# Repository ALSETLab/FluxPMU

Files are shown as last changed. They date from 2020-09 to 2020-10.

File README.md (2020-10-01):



# FluxPMU - An Open Source Maker's Guide of an DIY PMU
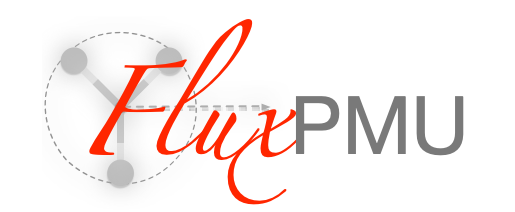
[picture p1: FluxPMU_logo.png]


FluxPMU is a "grassroots" educational project that aims  to  enable  students  to  explore  and  buildan  open  source,  low  cost  PMU.  

Building  from  the  legacy  of [OpenPMU  V1](https://ieeexplore.ieee.org/document/6463452),  FluxPMU  provides  a Do-it-Yourself (DIY) guide with  all  documentation  and  software  sources  required  to  build FluxPMU.

FluxPMU provides only a refinement of OpenPMU V1's design, and it is NOT to be viewed as an evolution on the design of OpenPMU. For the latest iteration of the OpenPMU device, please visit: [http://www.openpmu.org/](http://www.openpmu.org/).

## Cite this work:

This repository is accompanied by a draft of the paper:
> E. Williamson, L. Vanfretti, P. Adhikari, J. W. Dziuba, and D. Laverty, “FluxPMU - A Maker’s Guide of a DIY Synchronized Phasor Measurement Unit,” submitted for review, IEEE PES ISGT NA 2021, Feb. 15-18, Virtual Event, 2021.

The paper can be found on this ``root`` directory, it is named [20200930_Overview_draft.pdf](https://github.com/ALSETLab/FluxPMU/blob/master/20200930_Overview_draft.pdf). The paper has been submitted for review to the [IEEE PES ISGT NA 2021](https://ieee-isgt.org/), if and when the paper is published, this repository will be updated to provide a link to the final version of the paper.

When citing the paper above, we also recommend citing the following publication:
> D. M. Laverty, R. J. Best, P. Brogan, I. Al Khatib, L. Vanfretti and D. J. Morrow, "The OpenPMU Platform for Open-Source Phasor Measurements," in IEEE Transactions on Instrumentation and Measurement, vol. 62, no. 4, pp. 701-709, April 2013, doi: 10.1109/TIM.2013.2240920.

## Repository Organization

### Where to start?
After reading the paper(s) listed above, the entire "Maker's Guide" can be found in the director ``./00_Documentation/00_Makers Guide.pdf``, this will give you an overview of the different resources associated with this repository.

### Organization
This repository contains more than the main "Maker's Guide", it also provides updated source code for all software required for the FluxPMU, documentation for the software, hardware assembly guides, etc.

The resources have been organized as follows:
  - ``00_Documentation`` this is the major folder, it includes the "Maker's Guide" as a single .pdf, [20200930_Overview_draft.pdf](https://github.com/ALSETLab/FluxPMU/blob/master/20200930_Overview_draft.pdf), and three sub-folders. The sub-folders include:
      - ``01_HardwareGuides`` contains assembly instructions, PIC micro-controller configuration, wiring, etc.
      - ``02_TestingGuides`` contains documents showing how to test the FluxPMU using different instruments such as a frequency generator, an Analog Discovery Board, etc.
      - ``03_LabVIEW_VI_Documentation`` contains individual documentation for all LabVIEW VI files in .pdf. You can also find this documentation [online](https://alsetlab.github.io/S3DK/docs/Code_Flow_Chart.html), however, it is also placed here for version tracking and maintainance purposes.
  - ``01_SourceCode`` contains two folders, one with all the updated (64-bit) software related to LabVIEW and the PIC micro-controller (v5p1) files used.
  - ``02_HardwareSourceFiles`` contains a part list/bill of materials with costs based on US-based suppliers and costs in US dollars, as well as the design BRD files for the PCBs.
  - ``10_LegacyDocumentation`` contains the original documents we used when getting FluxPMU started.

## Acknowledgement
This work was supported in part by Dominion Energy Virginia and in part by the Center of Excellence for NEOM Research at the King Abdullah University of Science and Technology under grant OSR-2019-CoE-NEOM- 4178.12.

## No Warranty
(c) David Laverty, Emmett Williamson, Luigi Vanfretti, Prottay M. Adhikari, Jerry W. Dziuba.

All materials under this repository are distributed under the GPL v3 license.

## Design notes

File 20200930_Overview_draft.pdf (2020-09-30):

# FluxPMU — A Maker’s Guide of a DIY Synchronized Phasor Measurement Unit

Emmett Williamson, Luigi Vanfretti, Prottay M. Adhikari, Jerry W. Dziuba
ECSE Department
Rensselaer Polytechnic Institute Troy, NY, USA
email: emmettact@gmail.com, vanfrl@rpi.edu, mondap2@rpi.edu, dziubj@rpi.edu

David Laverty
Energy, Power and Intelligent Control Queen’s University Belfast Belfast, UK
email: david.laverty@qub.ac.uk

Abstract—Synchrophasor technology is transforming the way the power grid is being monitored thanks to the benefits provided by synchronized Phasor Measurement Units (PMUs). To exploit these benefits, future power engineers need better understanding of how PMUs work at all levels, from hardware components to phasor estimation methods implemented in software. However, hands-on experiences with these technologies allowing students to ”tinker” with a PMU are limited. The FluxPMU project aims to enable students to explore and build an open source, low cost PMU. Building from the legacy of OpenPMU V1, FluxPMU provides a Do-it-Yourself (DIY) guide with all documentation and software sources required to build the FluxPMU, which can be found in the following Github repository: https://github.com/alsetlab/fluxpmu. This paper summarizes the authors’ efforts in creating this Maker’s Guide.

I. INTRODUCTION
A. Motivation

Major power system outages, such as 2003 Northeast Blackout [1], 2012 India Blackout [2], 2014 Bangladesh Blackout [3], 2019 London Blackout [4], have highlighted the advantages of high update rate and time synchronized measurements for system awareness. One of the main ways this is achieved is through Phasor Measurement Units (PMUs), which produce time sycnhronized synchrophasor measurements. It has been suggested that, implementing more Phasor Measurement Units (PMUs) could have helped control the power loss by providing grid operators with more information in all those cases. It is to be noted that, although nine PMUs were in use during the blackout reported in [2], two of them (in crucial locations) were not connected to communicate with control centers. The reports associated with these blackouts, suggest that these systems lacked situational awareness and system visibility . As the number of installed PMUs increases in the United States [7], modern PMUs are considered to be a black box of digital signal processing. For instance, industry grade protective relays with PMU functionalities or standard PMUs provide the necessary functionalities, but are difficult to adopt for teaching applications as it is challenging to tinker with their

This work was supported in part by Dominion Energy Virginia and in part by the Center of Excellence for NEOM Research at the King Abdullah University of Science and Technology under grant OSR-2019-CoE-NEOM-4178.12.

internal hardware and functions beyond configuration changes without risking potential damage. Another constraint is that the cost of industry-standard PMUs are over $7000 USD [8], which is too expensive for educational purposes. Additionally, an industrial grade PMU requires special setup to be safe. Using main power line voltage, current and power, poses safety requirements difficult to fulfill in a classroom setting.
The main requirements to consider for an educational PMU are: (i) low cost, (ii) ability to expose students to hands-on learning on the inner workings of the devices, (iii) safety, and (iv) adequate documentation. While the industry grade devices offer plentiful documentation, they do not fulfill requirements (i)-(iii). On the other hand, several open source PMUs that have been created could offer a solution to the cost, but lack the documentation for students use. FluxPMU aims to solve these issues.
FluxPMU is an open-source, low-cost PMU suitable for educational purposes. Being an open source hardware-software solution, FluxPMU would enable the students to explore and modify the entire signal path. Students will have the opportunity to configure and readjust hardware components like CTs and PTs, burden resistors, etc. It is also possible to have direct access to the ADC stage, where analog signals are converted into digital measurements. Apart from hardware and software, the FluxPMU project consists of a documentation dedicated to the build process. The documentation was written specifically to be used by students to ameliorate the build process, and help improve the understanding of each component, and how a PMU works. However, it must be noted that this implementation requires the students to have electrical safety training, as it involves working with high voltages.
B. Previous and Related Work
FluxPMU is based on OpenPMU V1 [9], [15], [16]. OpenPMU V1 has the main benefit from educational purposes to expose the student to all software and hardware aspects that need to be considered for a functional PMU. National Instruments has archived the OpenPMU V1 project [24] in their library. The authors have collaborated to build on the legacy of OpenPMU V1 for educational purposes, and thus, the hardware and software is nearly identical between FluxPMU and OpenPMU. The main difference is that the documentation provided by FluxPMU will offer a more comprehensive guide specifically tailored for students and educational purposes. The main criticism of OpenPMU V1 [11] and thereby of FluxPMU is that of the use of a National Instruments (NI) 6009 Data Acquisition (DAQ) and the NI LabVIEW [10] software being proprietary. While the dependency on the NI 6009 still remains an issue, the dependency on LabVIEW is now less important as NI has released LabVIEW Community Edition in 2020 which provides full featured access for open source projects, however, using this design in a classroom setting would require the University to have licenses available. This last aspect is not of concern for the authors’ institutions, which have LabVIEW licenses, and similarly for many other institutions that also subscribe to NI’s educational licensing programs.
OpenPMU V2 [17] reports a next generation design replacing the paradigm used in OpenPMU V1, which addresses the previous limitations by using low cost Single Board Computers (SBCs), mainly the Raspberry Pi and the BeagleBone Black. It is a truly open source and open hardware PMU project, and estimated to cost only around $200 USD [7]. However, the technology stack used for this project is too complex for its use in an educational setting at the undergraduate level. Other than OpenPMU, it is difficult to find open source, low cost PMU designs suited specifically for students. Several other low-cost PMU designs have been created [11]. Designs, such as FluxPMU, emerge from the pre-SBC era, for example GridTrak PMU from Arnold Stadlin [18] is a classic micro controller-based device that performs all computations in an integrated board, while the DTU-PMU developed at Technical University of Denmark [19], [20] uses a combination of a DAQ, a DOS computer and a Windows 2000 computer. While FluxPMU and GridTrak designs are still possible to build and further develop, the rapid advances of SBC make their integrated features more attractive for new designs. This is evident in the new OpenPMU V2, PhasorsCatcher [11] and the recent efforts from RWTH Aachen University LOCO. A similar implementation was carried out in [23]. However, most of these projects have focus on producing a low cost PMU, while they are unsuitable for educational purposes as they offer limited or no documentation on how to build the PMUs by oneself, with exceptions (GridTrak and OpenPMU V2). OpenPMU V1 utilizes NI LabVIEW, which uses its ”graphical programming environment” for easy visualisation of data within the LabVIEW environment. But, the main drawback of V1 is that the sampling clock of the NI-DAQ can’t be synced directly to the GPS time source. This limitation is solved in the OpenPMU V2 hardware with the introduction of a GPS disciplined ADC unit inside the Data Acquisition (DAQ) System [25]. However, this hardware is predominantly driven through command-line and lacks an easy ’graphical interface’. Thus, OpenPMU V2 somewhat requires skills beyond those expected from undergraduate students.
Another option to implement a PMU for educational purposes is through the use of a National Instrument (NI) Compact Reconfigurable Input/Output (CRIO). By selecting input modules that collect voltages and a timing GPS signal, the

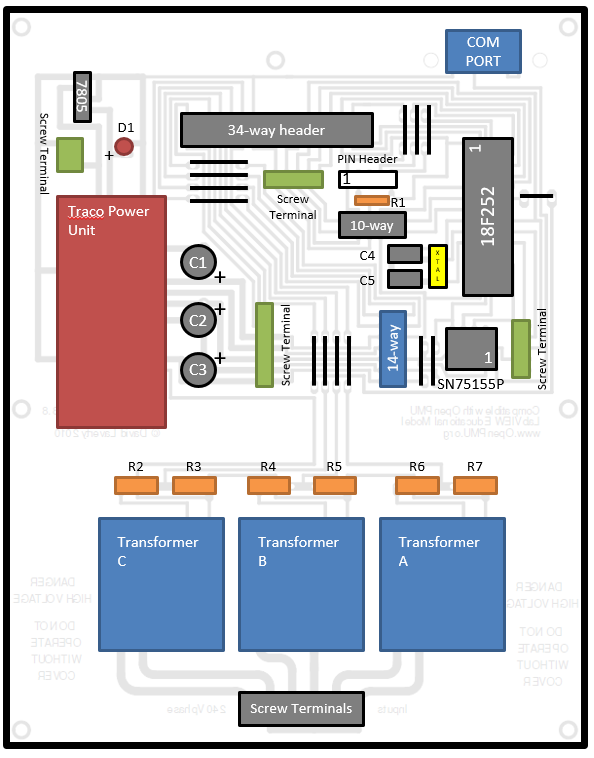
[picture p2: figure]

Fig. 1. Hardware layout for the circuit board components of FluxPMU

software run on the FPGA used by a CRIO could model a PMU [14]. However, there are several problems in using a CRIO. First, is the cost of both a CRIO and the modules themselves would easily cost more than other open source hardware examples. Secondly, the CRIO PMU would be mostly software driven and not offer exposure to any other sort of applicable hardware involved in a PMU other than configuring and programming the modules. This can result in a misunderstanding of the importance of both software and hardware aspects in PMUs. Thirdly, CRIO hardware has a steeper learning curve, specially for undergraduate students.

C. Contribution
- The entire build process, and all unexpected issues associated with have been documented, along with solutions and work around that were found. The documentation for the build process has been consolidated in a Maker’s Guide in an attempt to improve ease-of-use and facilitate a student’s experience building FluxPMU.
- All of the software associated with FluxPMU was documented to give students a better understanding of what happens behind the scenes. Additional software was also added to give students more resources to understand how FluxPMU works.
- The FluxPMU project adds documentation and work through guides to all of the hardware associated with building the project, along with examples of how FluxPMU was built in the ALSET Lab of Rensselaer Polytechnic Institute.

II. BACKGROUND

A Phasor Measurement Unit is a device that measures the voltage and/or current in power lines based on phasor representation of those periodically varying quantities. In measuring the phasor, a PMU produces a synchrophasor measurement by combining the phasor measurement with a time stamp. In most cases, PMUs combine results from several measurementwindows in order to publish a single output value. Time stamps typically come from Global Positioning System (GPS) satellites. In doing so, power grid operators can use the time synchronous measurements to perform more accurate data collection and analysis when multiple PMUs are used. A complete treatment of PMU technology is outside the scope of this work. A more comprehensive background information on PMUs is provided in [22], [9].

III. HARDWARE

The implementation of FluxPMU can be broadly separated into two parts,
- An electronic board for the acquisition of electrical signals. NI 6009 DAQ is used for acquiring the signals and converting them from analog to digital quantities.
- Algorithms implemented in LabVIEW that acquire the data for phasor estimation executed within a PC.
A simplified system diagram of FluxPMU is shown in Fig.3. The hardware for FluxPMU consists of an assortment of components for the circuit board itself, along with several external devices. The bulk of the hardware comes from the components that are soldered on to the FluxPMU board, as shown in Fig. 1. This board is a standard HV-transducer board. A comprehensive list of these components is shown in the bill of materials (within the Maker’s list). The basic layout for the circuit board hardware is shown in Fig. 1. It is important to note that, this part of the work requires the usage of high-voltage equipment, which should be used only under the supervision of a qualified individual.
The external components consist of the following:
A. PIC 18F2525

The PIC micro controller is used to work with the GPS NMEA signals received via the RS-232 standard, and output a code used by FluxPMU. Additionally, the PIC micro controller generates the 60 Hz (or 50 Hz) pulse train that triggers the NI-6009. Once the PIC records the NMEA data, it parses through that data to retrieve the time information. The PIC micro controller essentially enables the time transfer to the PC. The way this is achieved is that the NI-DAQ toggles a pin momentarily high, and records the CPU counter value (of the order of nanoseconds) at the moment this happens. The PIC sends a message by the RS232 port to LabVIEW to tell LabVIEW the time of day that it saw the rising edge. LabVIEW then extrapolates the time from the CPU counter. The major hardware constraints in this approach are, the latency of the LabVIEW code, the latency of the USB bus, and the NI DAQ.

A programmer along with some additional software from Microchip Technology are required to program the PIC micro controller. The programming hardware is a PICkit 3, which connects to 5 of the PIC 18F2525’s pins. To run the programmer, Microchip’s MPLAB IDE is used. Although, it must be noted, that the 1PPS of the GPS connects directly to the PIC, which does the time-transfer, and enables the PMU for time synchronous measurements.

B. GPS Reciever

A GPS receiver is required to implement this hardware. In this particular implementation a Germic 18x integrated GPS receiver and antenna was used. The location data is transmitted via National Marines Electronics Association’s (NMEA) 0183 ASCII interface specification [12] and uses the RS-232 standard to send the location information to the PIC micro controller. The Garmin hardware sends navigational information in NMEA format, which contains the crucial timing-information required for PMU operation [12]. It needs to be noted, that the NI-6009 receives the timing information for debugging purposes, which would be useful specially when the substation is in a remote location.
The time transfer comes in the form of a 1 Pulse-Per-Second (1PPS) signal. This signal is sent directly to the PIC micro-controller, which is supposed to generate the 60 Hz pulse trainthat will trigger the NI-6009. If the NI-6009 fails to receive the trigger, LabVIEW will get stuck. It is worth noting that, this part of the setup is responsible for enabling the time-transfer, which is crucial in terms of the operation of the PMU. Without the functional time-transfer the PMU will not be able to work.
C. NI USB-6009 OEM

The NI 6009 is a multifunction Input/Output (IO) device that provides DAQ functionalities which are easily accessed through a host computer running different NI software, including LabVIEW. In other words, it acts as a data acquisition board which records the input voltage signals through three analog input pins. It is able to produce 14 bit long digital outputs at a rate of 48 kS/second.The digital I/O pins can be accessed in order to develop a real-time control system development such as the one reported in [26]. Additionally, the NI 6009, receives the 1PPS timing signal that can be used for debugging purposes only. The NI 6009 DAQ is interfaced with the host computer via a standard USB cable.

D. Power Supplies and Other Hardware

An external power supply is required to complete the construction of the FluxPMU hardware. The power supply has an input of 100-240 V AC supply with a maximum current rating of 1.2 A and a frequency rating of 50/60 Hz. The output is rated at 12 V, 4.5 A. In this particular implementation MeanWell HDR 60-12 power-supply unit was used. The wiring connected to it used standard gauge 22 wire.

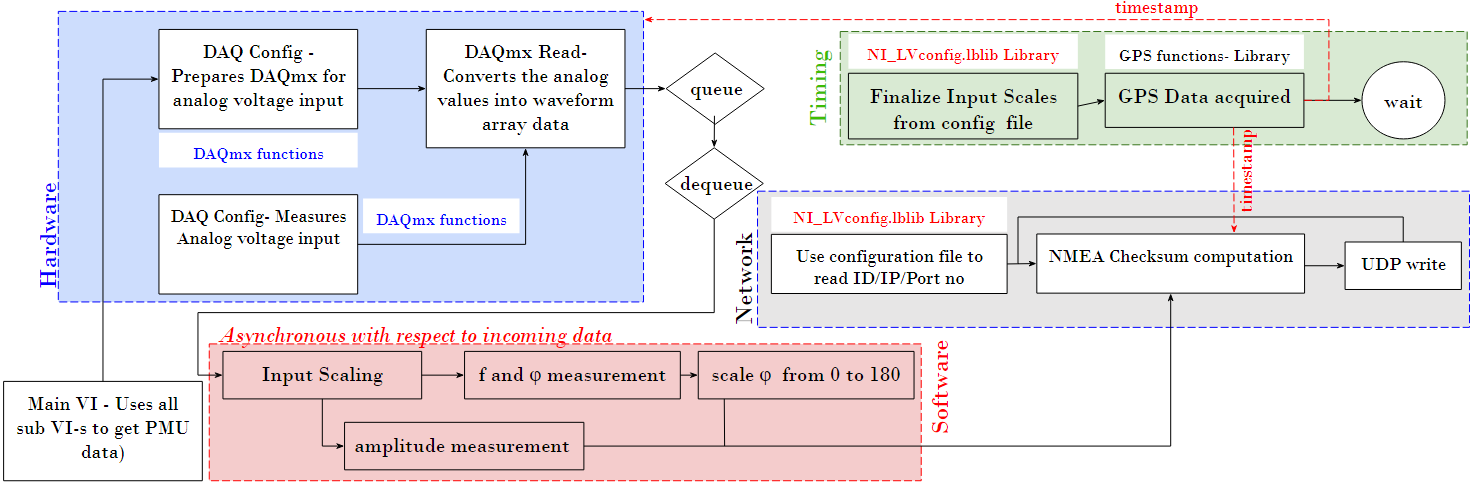
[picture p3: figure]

Fig. 2. Algorithmic Flowchart for the FluxPMU

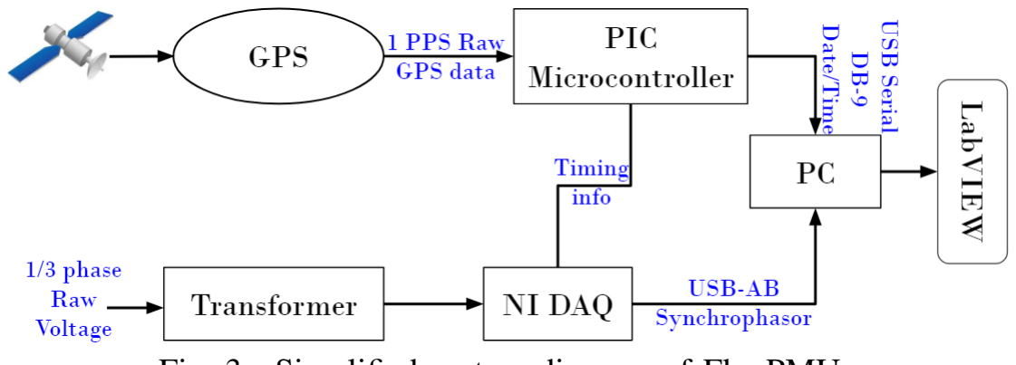
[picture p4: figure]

Fig. 3. Simplified system diagram of FluxPMU

Overall Assembly
The steps required to assemble the hardware have been documented in the Maker’s Guide and are summarized in section V. The simplified flowchart of FluxPMU in Fig. 2 summarizes how different VIs communicate with each other and complete the overall algorithm to compute the PMU data. The operations performed by these VIs can be classified into four different categories. In Fig. 2
- The blue box contains all the data acquisition functionalities,
- The red box includes the software based signal conditioning and scaling functionalities,
- The grey box contains the network functionalities,
- The green box contains the timing functions.
In summary, the PMU system starts up by receiving the raw voltage and GPS time signals simultaneously. The 1PPS received from the GPS is utilized by the PIC micro-controller to generate time-synchronous measurements for the PMU. The data acquisition and analog-to-digital conversion is done by a DAQ board from NI. Once all of the data processing has been complete, the GPS time stamp signal and voltage measurements are formatted as synchrophasors in LabVIEW.

IV. SOFTWARE
The software to drive FluxPMU is based on the NI G programming language of the LabVIEW software. G is a graphical programming language, designed for systems engineering and real time applications [10]. Within LabVIEW, a Virtual Instrument (VI) is the basic building block of programs written in the G language. A VI consist of a front panel which acts as a graphical user interface, and a block diagram that consists of the graphical programming blocks. An example of the front panel for FluxPMU is shown in Fig.5.
Before running the main VI which utilizes all the other subordinate VIs, a few LabVIEW specific drivers including NI DAQmx Driver, NI VISA Driver, and LabVIEW Real Time need to be installed on the system. Once these are resolved, FluxPMU software can be opened in LabVIEW. Once opened, there are several configuration settings that need to be taken care of, as shown through the example from the Maker’s Guide.
There are are 18 additional VIs that are used to set up configuration files, performing computations, and displaying, storing and if desired, reporting of PMU data via UDP with a simplified data frame which is based on NMEA. Since, the

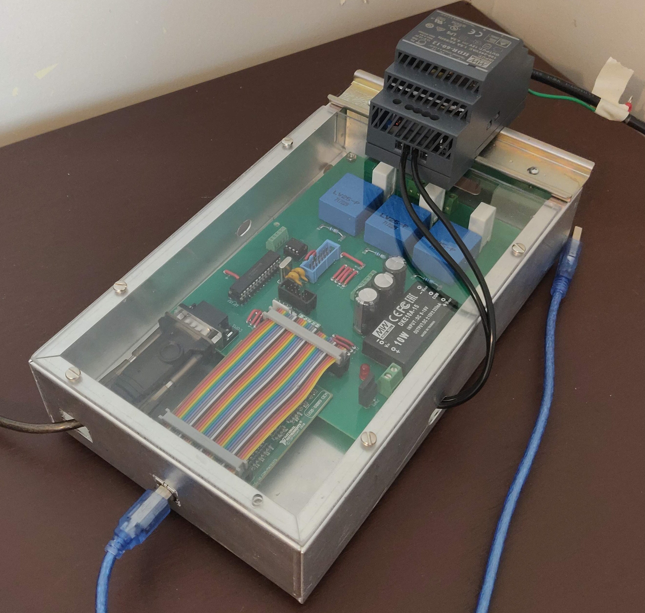
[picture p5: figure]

Fig. 4. Hardware prototype of a fully operational FluxPMU.

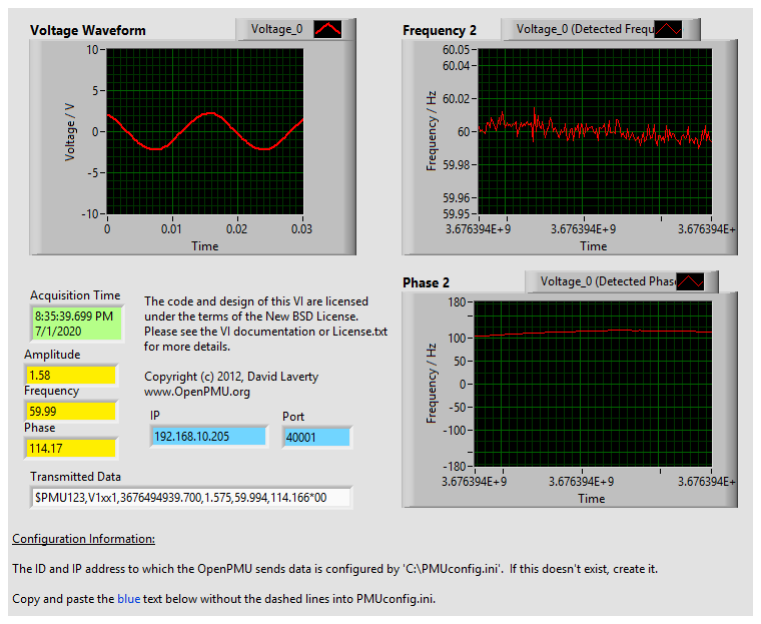
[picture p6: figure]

Fig. 5. A fully operational FluxPMU with the front panel for the single phase software with a single phase input

GPS stage uses the same NMEA specifications, it would be easier for the students to work with this data as they are already familiarized with it.

V. ASSEMBLY

The process to assemble all of the components in order to run the FluxPMU are detailed throughout the Maker’s Guide. The following summarizes the main steps of the process:
1) Decide on a version of FluxPMU and order the required parts and make/order the printed circuit boards, i.e. 1φ or 3φ voltages.
2) Download and install all of the necessary software and become familiar with the code.
3) When parts arrive, complete each individual external hardware component, and attach circuit components to the board.
Once FluxPMU has been completely assembled it should resemble the prototype in Fig. 4. To acquire measurements, the GPS antenna should be placed following the recommendations in [21], the voltage signals should be connected to the board’s input, and the USB cable to the computer. Once this is done, after executing the main program, the front panel will look like that of in 5, which shows the input voltage waveform and all computed quantities.

VI. CONCLUSION

The purpose of the FluxPMU project is to enable students to explore and build an open source, low cost PMU. While there are several other open source, low cost PMUs available for further research, FluxPMU aims to tackle issues students may find when trying to build open source projects. By providing thorough documentation on the build and operation process, FluxPMU offers more to the student experience than other similar open source PMUs. All documentation and software sources required to build the FluxPMU can be found in the following Github repository: https://github.com/
alsetlab/fluxpmu .

REFERENCES

[1] https://www.energy.gov/oe/services/electricity-policy-coordination-andimplementation/august-2003-blackout
[2] Loi Lei Lai, Hao Tian Zhang, Chun Sing Lai, Fang Yuan Xu and S. Mishra, ”Investigation on July 2012 Indian blackout,” 2013 International Conference on Machine Learning and Cybernetics, Tianjin, 2013, pp. 92-97, doi: 10.1109/ICMLC.2013.6890450.
[3] M. A. Kabir, M. M. H. Sajeeb, M. N. Islam and A. H. Chowdhury, ”Frequency transient analysis of countrywide blackout of Bangladesh Power System on 1st November, 2014,” 2015 International Conference on Advances in Electrical Engineering (ICAEE), Dhaka, 2015, pp. 267-270, doi: 10.1109/ICAEE.2015.7506847.
[4] https://www.bloomberg.com/news/articles/2019-08-09/london-blackout-occurredamid-drop-in-wind-and-natural-gas-power
[5] R. F. Nuqui and A. G. Phadke, “Phasor measurement unit placement techniques for complete and incomplete observability,” IEEE Transactions on Power Delivery, vol. 20, no. 4, pp. 2381–2388, 2005.
[6] Wald, M. L. (2013, November 11). The Blackout That Exposed the Flaws in the Grid. Retrieved from https://www.nytimes.com/2013/11/11/booming/the-blackout-that-exposed-the-flaws-in-the-grid.html
[7] “Advancement of Synchrophasor Technology,” U.S. Department of Energy, Office of Electricity Delivery and Energy Reliability , Mar-2016. [Accessed: 20-Jul-2020]
[8] Schweitzer Engineering Laboratories, “SEL 421-4, -5 Instruction Manual.” 2016.
[9] D. M. Laverty, R. J. Best, P. Brogan, I. Al Khatib, L. Vanfretti and D. J. Morrow, ”The OpenPMU Platform for Open-Source Phasor Measurements,” in IEEE Transactions on Instrumentation and Measurement, vol. 62, no. 4, pp. 701-709, April 2013, doi: 10.1109/TIM.2013.2240920.
[10] “What is LabVIEW?,” NI. [Online]. Available: https://www.ni.com/en-us/shop/labview.html. [Accessed: 31-Jul-2020].
[11] D. Schofield, F. Gonzalez-Longatt and D. Bogdanov, “Design and Implementation of a Low-Cost Phasor Measurement Unit: A Comprehensive Review,” 2018 Seventh Balkan Conference on Lighting (BalkanLight), Varna, 2018, pp. 1-6.
[12] Garmin International Inc, “GPS 18x Technical Specifications.” Oct-2011.
[13] C. G. C. Carducci, et al, “A Versatile Low-Cost OS-based Phasor Measurement Unit,” 2019 IEEE International Instrumentation and Measurement Technology Conference (I2MTC), Auckland, New Zealand, 2019, pp. 1-6.
[14] P. Romano and M. Paolone, “Enhanced Interpolated-DFT for Synchrophasor Estimation in FPGAs: Theory, Implementation, and Validation of a PMU Prototype,” in IEEE Transactions on Instrumentation and Measurement, vol. 63, no. 12, pp. 2824-2836, Dec. 2014.
[15] D. M. Laverty, et al “OpenPMU: Open source platform for Synchrophasor applications and research,” 2011 IEEE Power and Energy Society General Meeting, Detroit, MI, USA, 2011, pp. 1-6.
[16] D. M. Laverty, L. Vanfretti, I. Al Khatib, V. K. Applegreen, R. J. Best and D.
J. Morrow, ”The OpenPMU Project: Challenges and perspectives,” 2013 IEEE Power Energy Society General Meeting, Vancouver, BC, 2013, pp. 1-5, doi: 10.1109/PESMG.2013.6672390.
[17] X. Zhao, D. M. Laverty, A. McKernan, D. J. Morrow, K. McLaughlin and S. Sezer, “GPS-Disciplined Analog-to-Digital Converter for Phasor Measurement Applications,” in IEEE Transactions on Instrumentation and Measurement, vol. 66, no. 9, pp. 2349-2357, Sept. 2017.
[18] A. Stadlin, “GridTrak OpenSource PMU (GTosPMU) Sensor.” [Online]. Available: https://github.com/ajstadlin/GridTrak. [Accessed: 7-August-2020].
[19] R. Garcia-Valle et al. “DTU PMU laboratory development — Testing and validation,” 2010 IEEE PES Innovative Smart Grid Technologies Conference Europe (ISGT Europe), Gothenberg, 2010, pp. 1-6,
[20] L. Vanfretti et al., ”Estimation of Eastern Denmark’s electromechanical modes from ambient phasor measurement data,” IEEE PES General Meeting, Providence, RI, 2010, pp. 1-8.
[21] North American SynchoPhasor Initiative, “A Guide for PMU Installation, Commissioning and Maintenance. Part II. PMU INstallation Procedures.” June 5, 2007. [Online] Available: https://www.naspi.org/sites/default/files/reference documents/ 81.pdf. [Accessed: 7-August-2020.]
[22] North | American | SynchroPhasor | Initiative, | Available: | https://naspi.org/
reference-documents
[23] Colin Chapman, Phaelan Guan, Tyler LeRoy, Ethan Miller, Dan Park, Wide Area Measurement System Utilizing Open Source Tools, Proceedings of The National Conference On Undergraduate Research (NCUR) 2013 University Wisconsin La Crosse, La Crosse, WI
[24] https://www.ni.com/en-us/innovations/white-papers/16/why-choose-ni-for-pmusand-wide-area-monitoring.htmlsection-537278404
[25] X. Zhao, D. M. Laverty, A. McKernan, D. J. Morrow, K. McLaughlin and S. Sezer, ”GPS-Disciplined Analog-to-Digital Converter for Phasor Measurement Applications,” in IEEE Transactions on Instrumentation and Measurement, vol. 66, no. 9, pp. 2349-2357, Sept. 2017, doi: 10.1109/TIM.2017.2700158.
[26] R. J. Best, et al, ”Synchrophasor Broadcast Over Internet Protocol for Distributed Generator Synchronization,” in IEEE Transactions on Power Delivery, vol. 25, no. 4, pp. 2835-2841, Oct. 2010, doi: 10.1109/TPWRD.2010.2044666.

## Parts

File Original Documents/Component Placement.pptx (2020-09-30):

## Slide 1

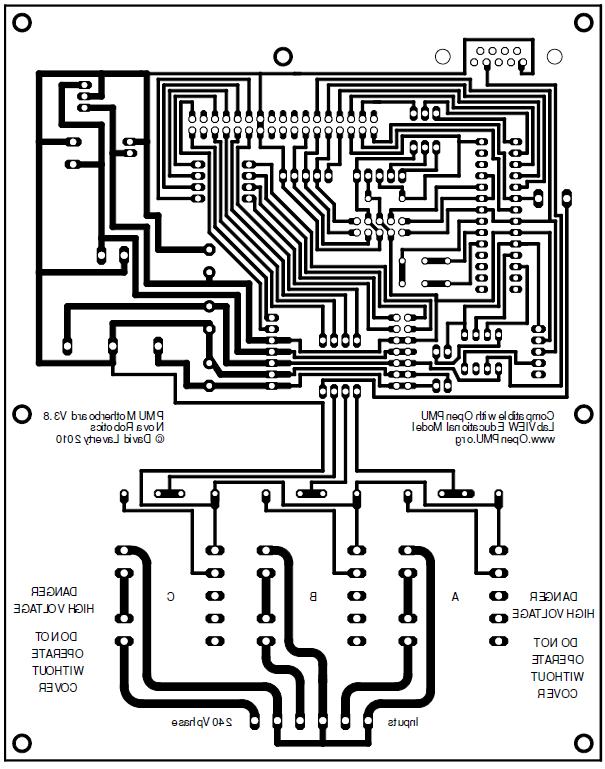
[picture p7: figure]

COM
PORT

D1 5V RED LED

C1 100 µF / 50 V
C2 100 µF / 50 V
C3 100 µF / 50 V
C4 100 pF
C5 100 pF

R1 100 kΩ
R2,4,6 430 Ω
R3,5,7 240 Ω

XTAL 4 MHz
Wire Link

7805

D1

34-way header

Screw Terminal

+

Screw Terminal

PIN Header

1

R1

1

18F252

Traco Power
Unit

C1

+

10-way

C4

C2

+

C5

XTAL

C3

+

Screw Terminal

14-way

SN75155P

1

Screw Terminal

R2

R3

R4

R5

R6

R7

Transformer C

Transformer B

Screw Terminals

Transformer A

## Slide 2

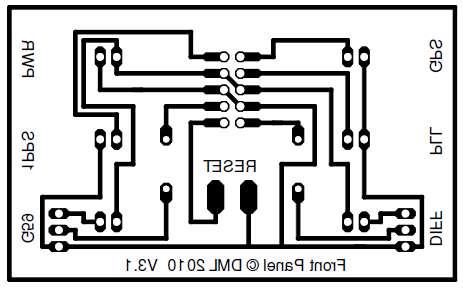
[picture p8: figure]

D1-D4 5V GREEN LED
D5 5V AMBER LED
D6 5V RED LED
R1,R2 240 Ω

T1,T2 NPN Transistor
(General Purpose)

D1

+

+

D2

10-way header

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
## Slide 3

18F252

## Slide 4

POWER

VT

DAQ

VT

VT

TIMING

RS232

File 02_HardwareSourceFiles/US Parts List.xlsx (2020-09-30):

Flux PMU | V2.5 | LEM T Sum: | $937.01 | Iso T Sum: | $765.78
 | Number of PMUs you want to build/ order:
 | 1 | LEM T Sum: | $937.01 | Iso T Sum: | $765.78
 | Only PMU, no extra components and # to build:
 | 1 | LEM T Sum: | $897.52 | Iso T Sum: | $726.29
Supplier | Description | Qty / PMU | $ / each | Total / Part | Part Number
National Instruments | USB-6009 OEM | 1 | $398.00 | $398.00 | USB-6009 OEM
 |  |  |  | $0.00
Digi-Key | 9-pin D-Type socket | 1 | $0.77 | $0.77 | AE10921-ND
 | USB-6009 OEM IDC Socket (2x17) | 1 | $2.52 | $2.52 | 19M5064
 | DIN Rail Bar (2m) | 1 | $7.14 | $7.14 | 277-7262-ND
 | PICkit 3 Programmer | 1 | $47.95 | $47.95 | PG164130-ND
 | (+ / - )15 Volt DC-DC Converter | 1 | $19.75 | $19.75 | 1866-1323-ND
 | Line Driver and Receiver | 1 | $1.95 | $1.95 | 296-6836-5-ND (https://www.digikey.com/product-detail/en/texas-instruments/SN75155P/296-6836-5-ND/370207)
 | Ribbon Cable | 1 | $3.30 | $3.30 | MC34M-1-ND
 | USB A to USB B Cable | 1 | $2.05 | $2.05 | AE10617-ND
 | Front Panel IDC Plug (2x5) | 1 | $0.94 | $0.94 | 571-1658621-1
CDW | GPS Receiver / Antenna (Garmin GPS18) | 1 | $84.99 | $84.99 | https://www.cdw.com/product/Garmin-GPS-18x-OEM-PC-GPS-receiver-module/1522526?cm_cat=GoogleBase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
 |  |  |  | $0.00
Mouser | 12V DIN mounted PSU | 1 | $19.97 | $19.97 | 709-HDR60-12
 | PIC Microprocessor 18F2525 | 1 | $5.40 | $5.40 | PIC18F2525-I/SP
 | 4 MHz Crystal | 1 | $0.33 | $0.33 | FOXSLF/040
 | 100pF Capacitors | 2 | $0.19 | $0.38 | VY2101K29Y5SS63V0
 | 5V Voltage Regulator (7805) | 1 | $0.91 | $0.91 | L7805CP
 | DC Bus Electrolytic Capacitors | 3 | $1.04 | $3.12 | ECA-1HHG102
 | Current Board IDC Socket (2x7) | 2 | $2.47 | $4.94 | 2-1761603-5
 | Wedding Ring CTs | 3 | $6.39 | $19.17 | CST-1010
 | Front Panel IDC Plug Strain Relief | 1 | $0.26 | $0.26 | 499252-5
Newark | USB to Serial Adaptor | 1 | $15.48 | $15.48 | 94C1223
 | 28-pin IC Socket (Tube 14) | 1 | $1.68 | $1.68 | 04M0623
 | 8-pin IC Socket | 1 | $0.18 | $0.18 | 53K0893
 | 34 Way IDC Plug | 2 | $1.15 | $2.30 | D89134-0131HK
 | 100k Resistor | 1 | $0.08 | $0.08 | CFR16J100K
 | 5-pin PCB header | 1 | $0.36 | $0.36 | 22-27-2051
 | 5-way 0.1" screw terminal | 2 | $2.10 | $4.20 | MPT 0,5/ 5-2,54
 | 7-way 0.1" screw terminal | 1 | $2.70 | $2.70 | MPT 0,5/ 7-2,54
 | 2-way 0.2" screw terminal | 1 | $1.12 | $1.12 | 1715721
 | 6-way 0.2" Screw Terminal | 1 | $2.67 | $2.67 | 282836-6
 | PIC Programming Cable | 1 | $3.00 | $3.00 | 56AC5693
 | LED - 5V Red (Power, Trip Occurred) | 2 | $0.41 | $0.82 | L-53ID-5V
 | DIN Rail Terminal Post - Red (1x VT, 2x CT) | 1 | $0.68 | $0.68 | 1SNK505062R0000
 | DIN Rail Terminal Post - Yellow (1x VT, 2x CT) | 1 | $0.71 | $0.71 | 1SNK506060R0000
 | DIN Rail Terminal Post - Blue (1x VT, 2x CT, 1x PWR) | 2 | $0.68 | $1.35 | 1SNK505020R0000
 | DIN Rail Terminal Post - Black (1x VT, 2x CT) | 1 | $0.61 | $0.61 | 1SNK505066R0000
 | DIN Rail Terminal Post - Green (1x VT, 1xCT, 1x PWR) | 2 | $0.71 | $1.42 | 1SNK506061R0000
 | DIN Rail Terminal Post - End Section | 1 | $0.24 | $0.24 | 1SNK505910R0000
 | DIN Rail Terminal Post - White (4x GPS, 6xAUX) | 1 | $0.68 | $0.68 | 1SNK505065R0000
 | DIN Rail Terminal Post - Clamp | 3 | $0.57 | $1.71 | 69H8492
 | Front Panel IDC Socket (2x5) | 1 | $1.87 | $1.87 | 2510-6002UG
 | Voltage Board IDC Plug (2x7) | 2 | $1.04 | $2.08 | 73K6216
 | Voltage Board IDC Plug Strain Relief (2x7) | 2 | $0.30 | $0.60 | 90F4185
 | Front Panel IDC Plug (2x5) | 1 | $0.72 | $0.72 | 1658621-1
 | LED - 5V Green (Power, GPS Lock, 1PPS, PLL) | 4 | $0.41 | $1.64 | L-53GD-5V
 | LED - 5V Amber (G59 Occurred) | 1 | $0.60 | $0.60 | SSL-LX3044YD-5V
 | Reset Button | 1 | $6.67 | $6.67 | 1203A2UL
OPTIONS
Your Choice | Motherboard V37 (Hall Effect) | 1 | ~70 | $70.00 | NA
Newark | LEM Hall Effect LV25 | 3 | $61.85 | $185.55 | LV 25-P
 | Burden Resistors (47k) | 3 | $0.17 | $0.50 | SQMR547KJ
 | Measurement Resistors (240 Ohm) | 3 | $0.32 | $0.96 | 78K5033
 | OR
Your Choice | Motherboard V38 (Isolation Transformers) | 1 | ~70 | $70.00 | NA
Newark | Isolation Transformers | 3 | $4.62 | $13.86 | 53X8379
 | Measurement Resistors (240 Ohm) | 6 | $0.32 | $1.92 | 78K5033

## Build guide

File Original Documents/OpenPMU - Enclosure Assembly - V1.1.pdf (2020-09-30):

# Open Source Phasor Measurement Unit

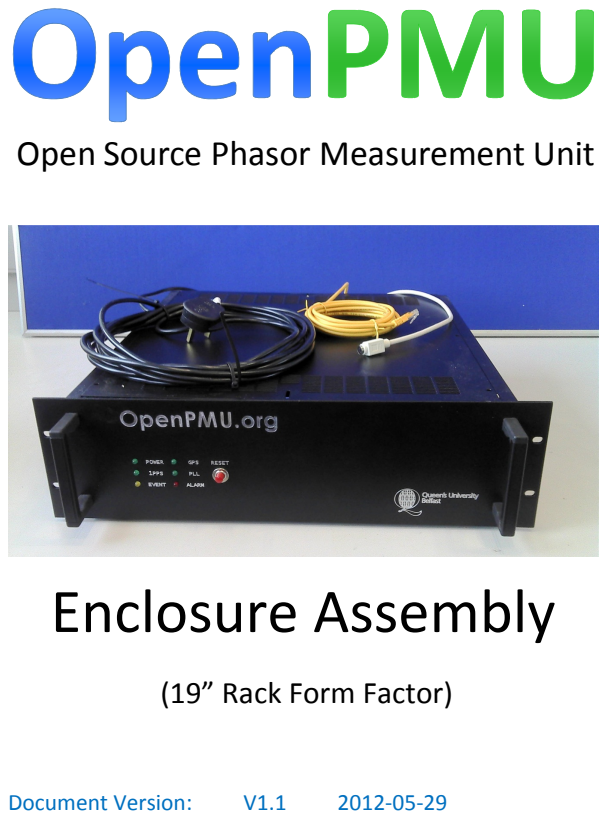
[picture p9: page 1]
Enclosure Assembly; Document Version:

(19” Rack Form Factor)

## Abstract:

### This document provides instructions on the assembly of an OpenPMU device using the National Instruments USB-6009-OEM data acquisition card and an

Acer Revo PC.

## Authors:

### Paul Brogan

### David Laverty

## Document History:

2012-05-29 | V1.1 Updated Title and Logo (This Version)
2012-05-28 | V1.0 Original Version

### Required Tools

Drill with HSS metal bit, 4mm.

Screwdriver and spanner, to fit bolts.

Electrical screwdriver to fit DIN rail terminals

Crimper

### Optional

Glue gun

### Cables

230V mains electrical cable, with plug or appropriate fitting, cable supplied with PC was cut and used in this circumstance.

1.5mm²
cable (Tri rated recommended) Red and black cable approx. 1m of each, yellow and blue cable approx. 600mm of each, yellow/green earth cable approx. 20mm.

Spade connector for grounding enclosure.

Ethernet Cat5 (or above) cable – sufficient length to reach router plus 500mm internal.

GPS antenna cable – sufficient to place GPS antenna in suitable location where GPS signals can be received plus 500mm internal.

### Additional

14 bolts, 3.5mm/6 Gauge (ideally with low profile heads) and nuts; to attach PCB, DIN rail, PC mount and PC power supply to enclosure; also 3 shock absorbing washers for use with PCB.

4mm – Ring Terminal/eyelet

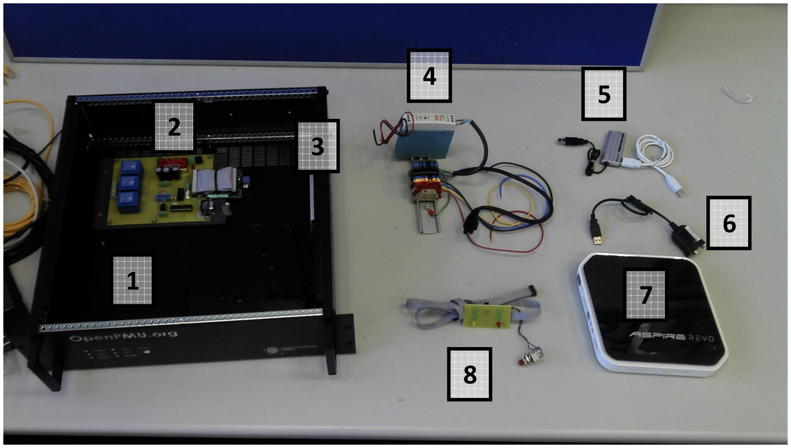
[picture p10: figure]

Fig 1 Necessary Components – one of each

1. 19’’ Rack enclosure, or similar enclosure fit for purpose.
2. Populated PCB and LabView DAQ, USB-6009-OEM.
3. Power supply for laptop (230VAC to 19VDC in this case) and mounting bracket (or cable ties)
4. 200mm of DIN rail, along with 7 DIN rail terminals, 3 DIN rail clamps and a 12VDC power supply.
5. USB hub/switch and USB to USB connector.
6. Serial to USB converter.
7. Acer Aspier Revo, Veriton or similar computer with suitable performance.
8. Front LED display, with reset switch and ribbon cable.

Fig 2

Bolt both the PCB and
Acer mount to the base
of the enclosure, bolt
the PC power supply to
the top, right hand side
(alternatively cable tie
utilising ventilation
holes) drill holes to
mount DIN rail. This
procedure will require
drilling with a 4mm HSS
metal drill bit.

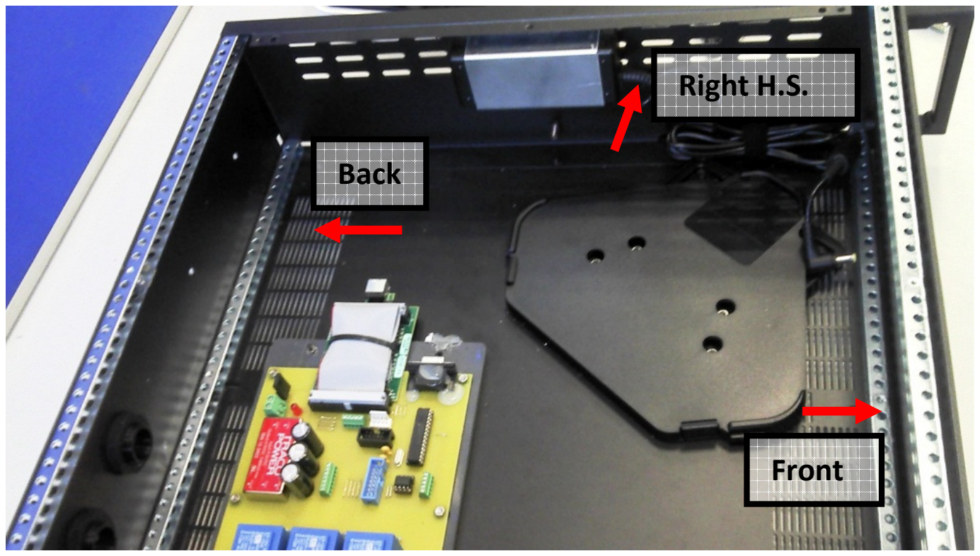
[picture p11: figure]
Front; Back; Right H.S.

Place PCB and PC mount in position, leave 40mm clearance between enclosure and object, orientate the so the connections are to the right hand side, as shown - mark holes. Separately place DIN rail in position, back right of enclosure, equal distance from top and bottom - Mark holes. Likewise with power supply bracket, place in the middle on the right at the top (as shown in Fig 2), ventilation holes can be utilised. Now drill all marked holes, 4mm. Bolt the PC mount and power supply; the bolt is fed in from the outside (low profile heads) and the nut is put on and tightened from the inside. For the PCB, place shock absorbing washers on the bolts between the enclosure and PCB. (The DIN rail must be populated before attachment)

Note! A bolt protruding beside the serial port will prevent connection, glue can be used.

Fig 3

Populate the DIN rail as shown in the picture.

From left to right, DIN rail clamp then red, yellow, blue and black DIN rail terminals, 2nd clamp, then, Brown, Blue, Green DIN rail terminals, then final clamp; finally the 12VDC power supply.

Firmly connect 600mm of red, yellow blue and black 1.5mm cable into the DIN rail terminals on the left that match their colour. (All connections to the bottom of the DIN rail terminals)

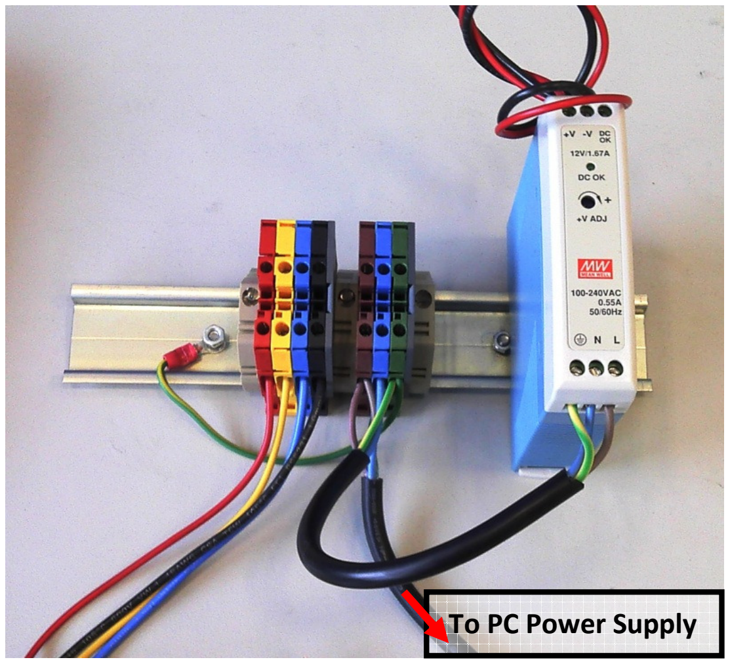
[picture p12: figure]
To PC Power Supply

Connect 100mm of 3 core mains cable into the power supply as shown, earth, neutral, live. The brown, blue and green (live, neutral and ground) DIN rail terminals in the middle must house the power cord to the 12VDC supply and the PC power supply – additionally 20mm of earth cable to be placed in the green terminal and a ring terminal crimped on the end, this will be bolted to the DIN rail and enclosure. All wires go into the underside; test for lose connections!

Fig 4

Connect power lead to PC transformer. Bolt the populated DIN rail to the back right of the enclosure, making sure to place ring terminal between the nut and DIN rail – thereby grounding the enclosure.

Place 400mm red wire into the +V output from the power supply, place

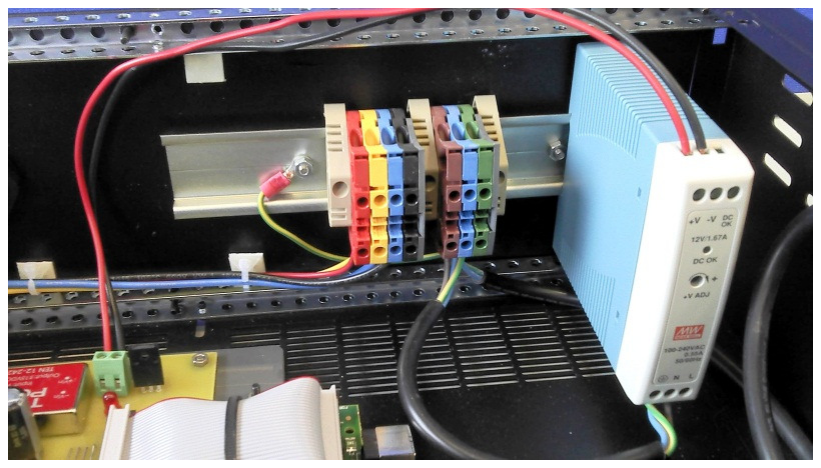
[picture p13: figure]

400mm of black wire into the -V output from the power supply. This is the power supply for the PCB and is attached as shown; attach the red, positive lead to the left hand side of the terminal and the black, negative side to the right.

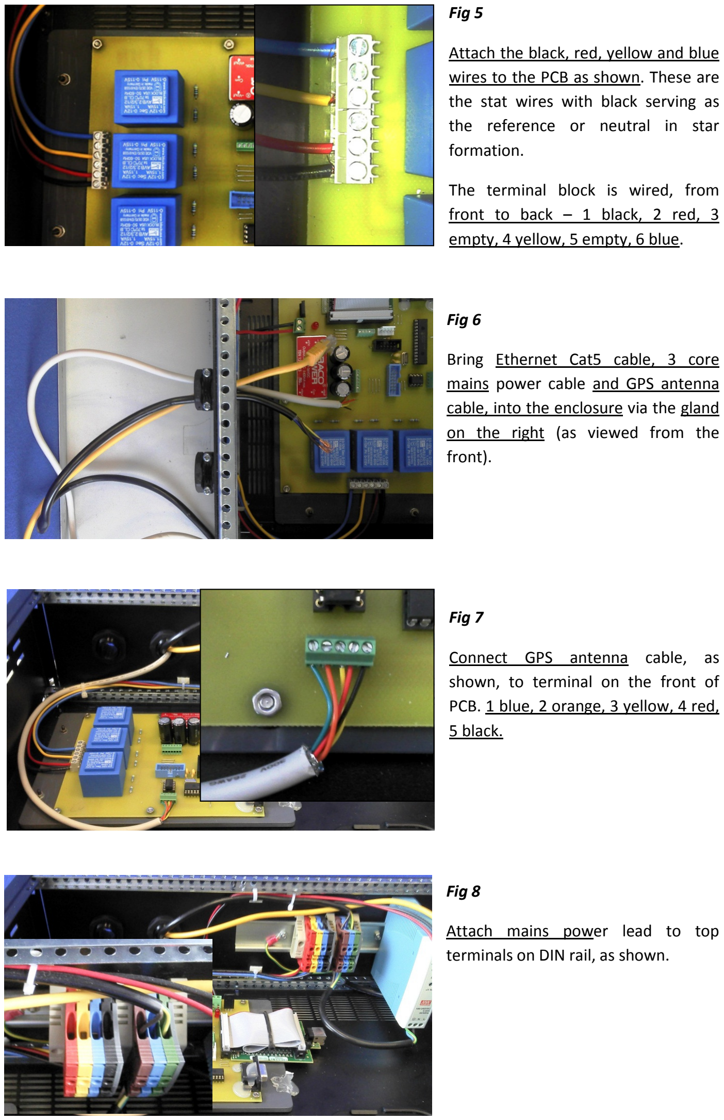
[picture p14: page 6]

Fig 5

Attach the black, red, yellow and blue wires to the PCB as shown. These are the stat wires with black serving as the reference or neutral in star formation.

The terminal block is wired, from front to back – 1 black, 2 red, 3 empty, 4 yellow, 5 empty, 6 blue.

Fig 6

Bring Ethernet Cat5 cable, 3 core mains power cable and GPS antenna cable, into the enclosure via the gland on the right (as viewed from the front).

Fig 7

Connect GPS antenna cable, as shown, to terminal on the front of PCB. 1 blue, 2 orange, 3 yellow, 4 red, 5 black.

Fig 8

Attach mains power lead to top terminals on DIN rail, as shown.

Brown to brown (live), blue to blue (neutral) and green/yellow to green (ground).

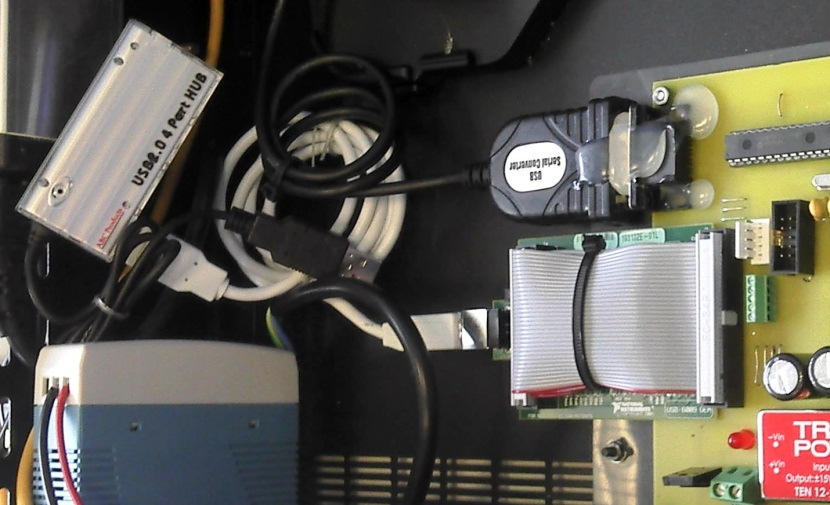
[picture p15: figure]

Fig 9

Insert serial to USB connection into RS232 slot on the PCB. Insert USB lead into DAQ, insert USB into USB hub.

(serial connection can be glued, especially if the unit may be subject to vibration)

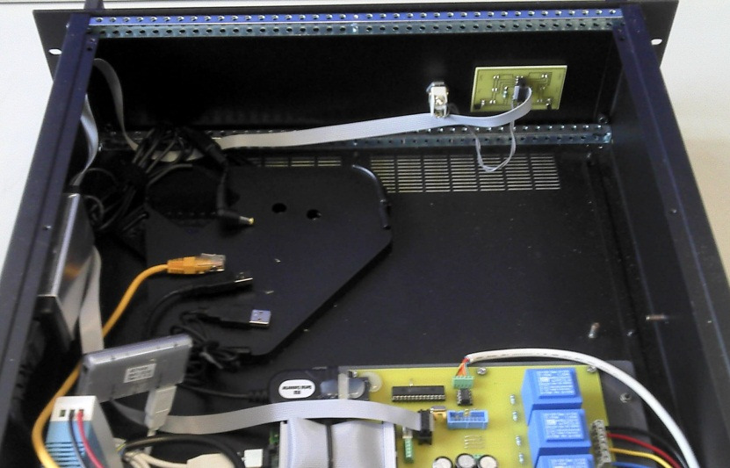
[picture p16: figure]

Fig 10

Push front LED display into machined holes, (Red LED to bottom left-Alarm) it should push in and hold securely.

Insert the reset button - unscrew nut before feeding through from the inside and rethreading nut.

Fit ribbon cable between display and PCB – top most pins on display connects to front pins on PCB.

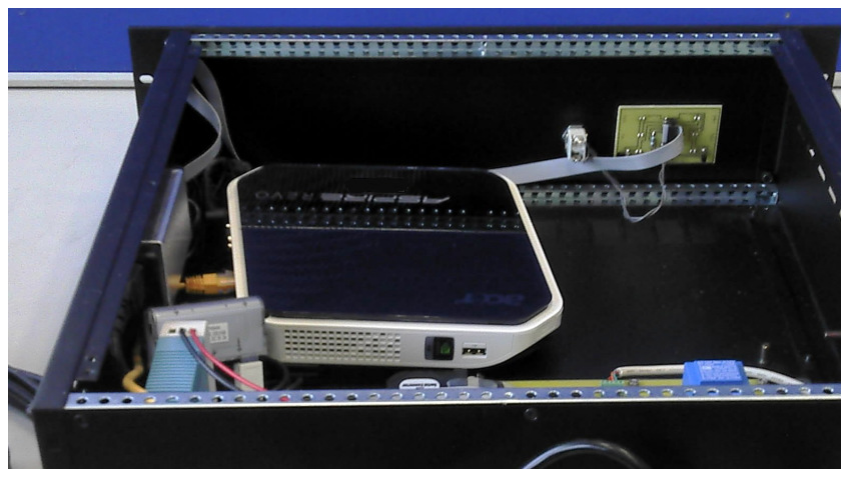
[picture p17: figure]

Fig 11

Insert Cat5 cable, USBs from hub and USB to serial connector finally the power cable.

Securely fit PC to its mount, it should be very secure and not pull off.

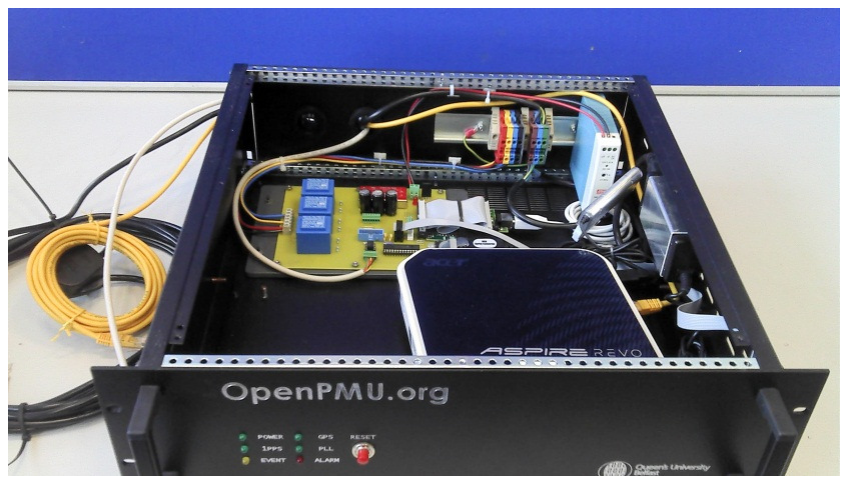
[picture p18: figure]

Fig 12

Tidy up lose cables with cable ties.

Excess Cat5, GPS antenna and mains power cable should be taken out through the gland and the cables clamped in position.

### Finally place lid on enclosure and screw down, Fig 13

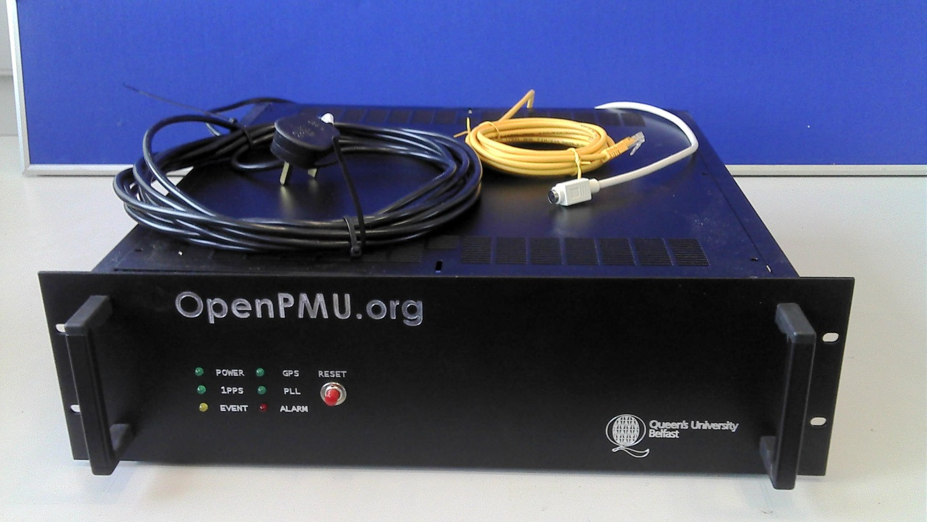
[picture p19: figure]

## Disclaimer

These notes are given as guidance for the assembly of the open PMU, fitted in a 19’’ rack. A very similar procedure will be followed if a different enclosure is to be used.

If you are assembling this unit it is assumed that you or a person involved is familiar with electrical equipment and electrical safety; the designers of the OpenPMU will accept no liability for injury, property damage, loss of data or income that may arise in the production, fitting and operation of this product.

Further documentation can be found at www.openpmu.org , have fun and get involved.

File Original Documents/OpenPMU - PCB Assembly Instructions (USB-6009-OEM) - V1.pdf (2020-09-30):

# Open Source Phasor Measurement Unit

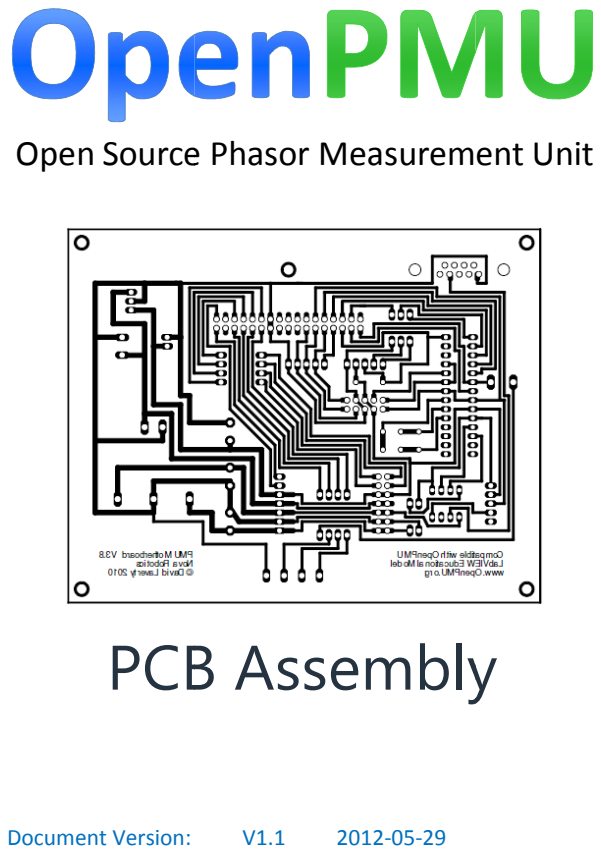
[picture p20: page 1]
PCB; Document Version:; Assembly

## Abstract:

### This document contains details you will need to fabricate and populate a PCB

for use with OpenPMU and a National Instruments DAQ (USB-6009-OEM).

## Authors:

### David Laverty

### Karl Weisser

## Document History:

2012-05-29 | V1.1 Updated Title and Logo (This Version)
2012-05-28 | V1.0 Original Version

OpenPMU PCB Assembly Instructions | V1.1

This document contains details you will need to fabricate and populate a PCB for use with OpenPMU and a

National Instruments DAQ (USB-6009-OEM).

IMPORTANT NOTE: These PCBs are for use at mains voltage. Do not assemble or use these unless you

are working in a laboratory environment and have appropriate safety training.

For hobbyists and those without safety training, use only the non-mains voltage model for signal

generators.

## Components

You will need to decide which version of the board you would like to assemble:

### 1. Hall Effect Model

| Can monitor mains supply (up to circa 260 Vrms)
| Very accurate
| Expensive

### 2. Transformer Model

| Can monitor mains supply (up to circa 260 Vrms)
| Fairly accurate, introduces small distortions at higher voltages
| Very cost effective

### 3. Signal Generator Model

| Best when monitoring mains supply is not requires
| Directly monitor voltages up to ± 10 Vpeak
| Safest for teaching environments
| Cheapest

Component listings for each model are available in the attached Excel file - click here.

## PCB Fabrication

Download the set of PDFs for the OpenPMU LEM PCBs - click here. PCBs are single sided and can be

produced in even basic PCB fabrication facilities. If you would like the PCBs in different formats, please

contact the author via the user account "clockdoctor".

Select and fabricate the PCB relevant to the design you would like to build.

There is also an optional front panel indicator PCB

also.

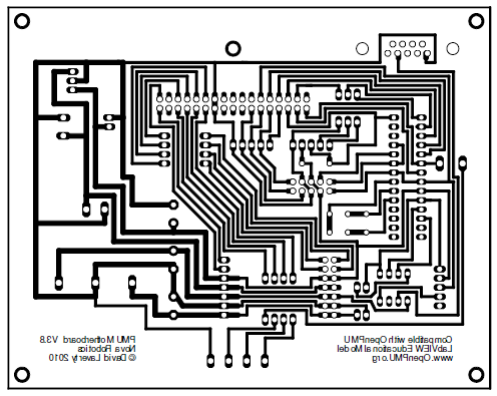
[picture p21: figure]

## PCB Population

Start populating the PCB, following the

### 1. IC holders

### 2. Screw terminal posts

### 3. IDC header posts

### 4. LEDs

### 5. Voltage Regulator

### 6. Capacitors

### 7. Resistors

### 8. TRACO power unit (necessary only for Hall Effects /

Once populated, insert the RS232 driver and the PIC

Attach the USB-6009-OEM using a bolt through the mounting hole. Make a

between the USB-6009-OEM and the PCB.

. It is recommended this PCB is fabricated and popu

component placement schematic by soldering the:

TRACO power unit (necessary only for Hall Effects / external signal conditioning)

18F252 microcontroller.

OEM using a bolt through the mounting hole. Make a ribbon cable to connect

lated

Apply a 12V power source to the power supply post. Check that the power LED indicator lights.

## PIC Programming

Once the PCB is fabricated and populated, you will need to programme the PIC microcontroller (PIC

18F252). To do so, you will need the Microchip ICD2 or compatible.

Download the source code (to follow), compile and build in MPLAB (www.microchip.com/) and download

to the microcontroller.

Note: Make sure that the ribbon cable is disconnected between the USB-6009-OEM and the PCB. Reattach

the ribbon cable once the microcontroller has been programmed.

## Testing

Download the test programme attached (to follow) to confirm that the various functions of the PCB are operating correctly.

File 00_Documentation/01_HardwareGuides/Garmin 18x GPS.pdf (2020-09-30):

### The Garmin GPS

Note: Whenever you use the GPS, you must make sure to place the GPS in a direct view of the sky. A lot of frustration has come from not placing the GPS in the correct spot. In my case, the GPS had to be taped on to a window to get the best signal. If you are having trouble getting a strong enough GPS signal, consider downloading a GPS testing app for Android or iPhone to try and find the best GPS signal for your workspace. You must also be sure to give the GPS enough time to find the signal, which can take anywhere between 5 and 10 minutes.

Before anything starts make sure that you have ordered the Garmin GPS 18x PC, not the USB or LVC. Once your GPS arrives, you will need wire cutters and strippers to set it up. Begin by cutting off the 12V car charger. Once cut, you will need to cut more of the outside insulator to get the power and ground wires free. This took some time and you must be careful to not cut the power and ground wires. I found that cutting at an angle was the easiest method to cut away the outside insulator. Strip and tin the power and ground wires. If you are unfamiliar with tinning wires, refer to the document Power Supplies Example for more information. To power the GPS, plug the wires into the ports shown below.

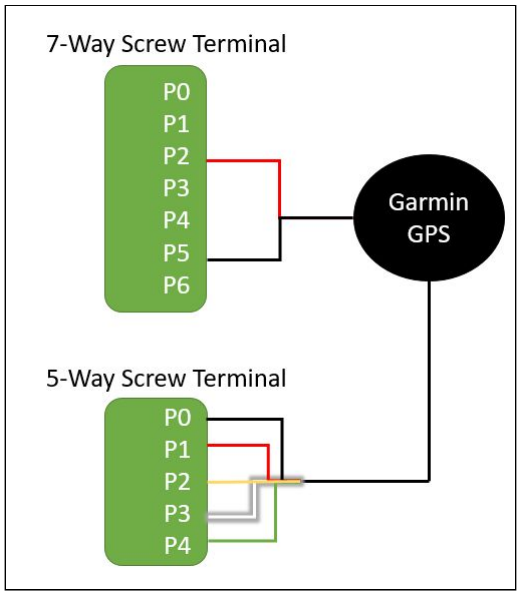
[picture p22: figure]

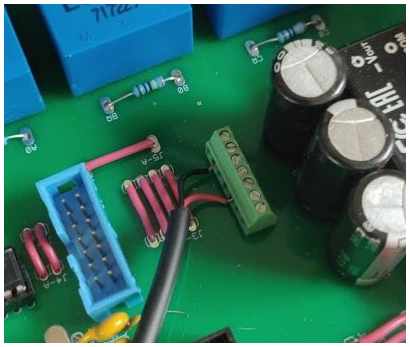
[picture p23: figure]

When first turning on the GPS, make sure it is placed right next to a window, or in a position to physically “see” the sky. As indicated by the manual, it may take several minutes to start up. Wait approximately 10 minutes, and open the VI 35 NEW GPS Interrupt RS232 Read and Windows Device Manager. In the Device Manager, expand the Ports (COM & LPT) to find what the GPS COM is. Once you know the COM, in the VI, set the Comm Port to that COM value. Run the VI. A GPS Time Code should be returned. Below is an example of how the power supply cables should be cut and stripped.

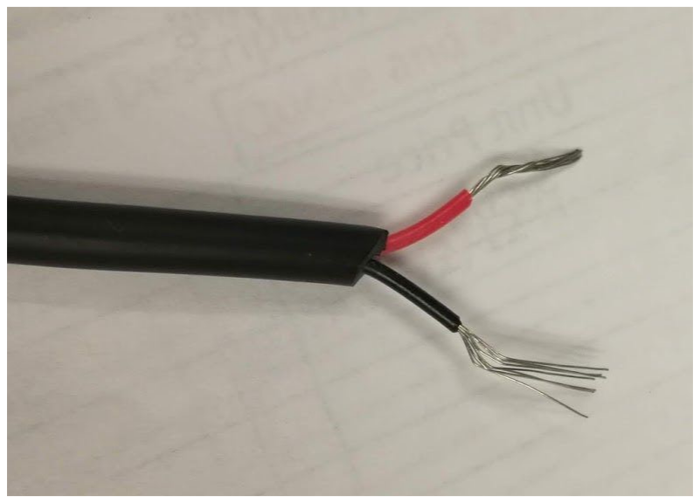
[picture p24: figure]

To set up the GPS to communicate with the board, you will need to start by cutting off the 9-pin connection (*). Once the 9-pin connection you will find 8 wires, as shown below.

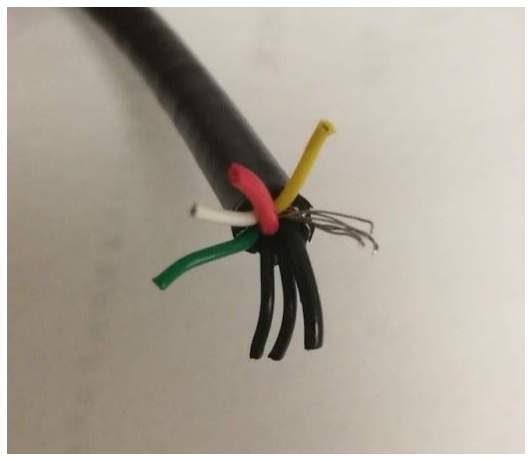
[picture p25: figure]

The wires data transfer are as follows. The information comes from the document OpenPMU -PCB Connections (USB-6009-OEM)-V1. Note, that the document OpenPMU - Enclosure Assembly -V1.1 states that the GPS antenna cable has a blue and orange wire. These cables must be from an old version of the Garmin 18x GPS, or a different GPS product all together.
- Red: Vcc 5V
- Yellow: 1 Pulse per second
- Green: RS232 in
- White: RS232 out
- Bare: A shield.
- Black (3): These are the ground wires.

Strip and tin each wire. Connect the wires to the terminal as shown to the right. Disregard connecting the bare wire. You will need to connect all three ground wires into the one terminal, which can be difficult to do. It is suggested to use a pair of tweezers if the wires are too difficult to manipulate with your hands.

(*) You can, if you want, directly connect the nine pin connector
to your computer via a USB cable. When doing this, OpenPMU
software will not work, but you can use the program Hyper Access

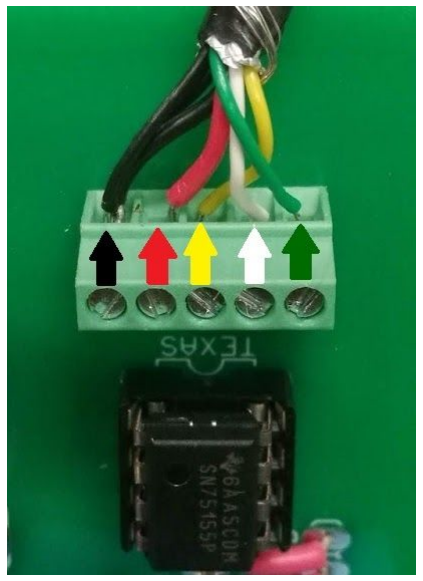
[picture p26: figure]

to test to make sure you are receiving the correct signal. The GPS time codes that are outputted directly from the Garmin are not the same as those used in OpenPMU. The time code is modified by the PIC18F2525, which is why directly plugging the Garmin into your computer does not work.

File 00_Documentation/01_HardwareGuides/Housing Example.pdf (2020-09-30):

Housing Build Example

The following document provides the steps taken to build a housing for FluxPMU for the ALSET Lab at Rensselaer Polytechnic Institute. There are several ways that you can build a final product, ranging from the example here, to the original 19” rack design shown in the document OpenPMU - Enclosure Assembly - V1.1.pdf.

FIgure 1: Final Product

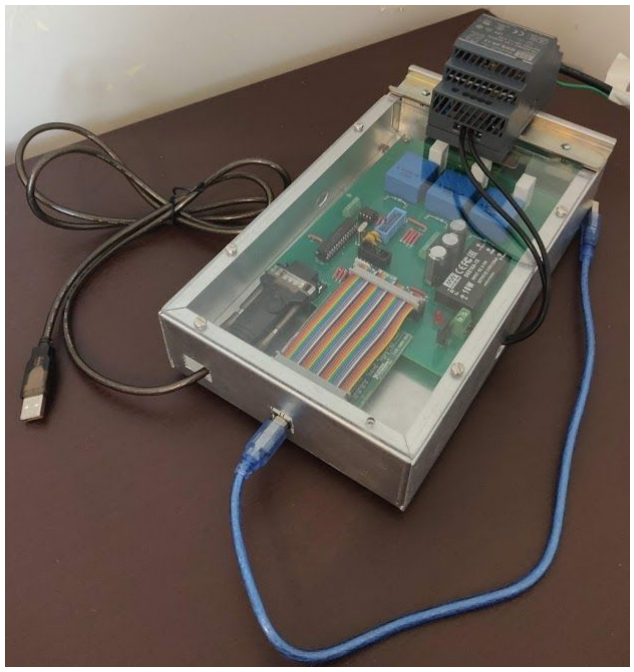
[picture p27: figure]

Figure 1 shows the final housing that was built to house FluxPMU. One note is that in the image above, the GPS is not shown.
To begin a similar build, you will need to acquire some sort of base box. McMaster-Carr (https://www.mcmaster.com/boxes/enclosures/) is a good place to start if you are looking to make a similar build as above. The housing in Figure 1 has a length of 10 inches, width of 6 inches, and height of 2 inches. The build began by drilling screw holes, and machining five holes for the cables to enter.

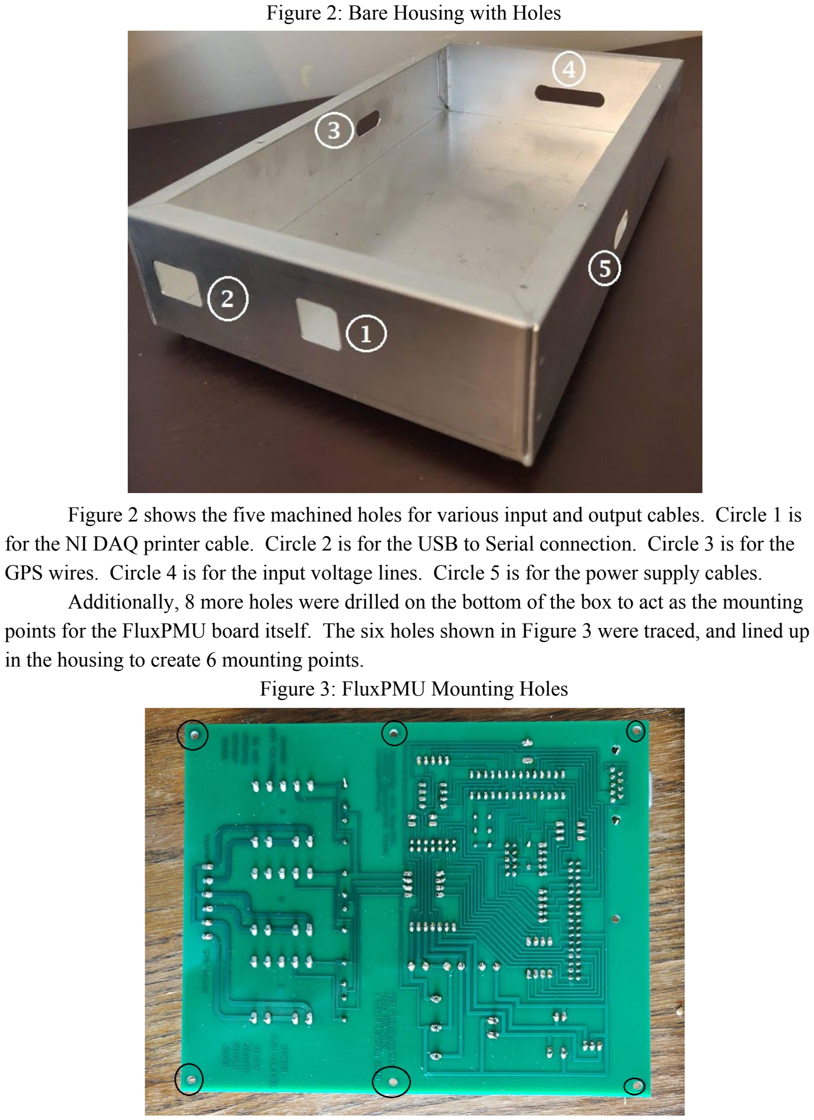
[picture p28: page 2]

Figure 2: Bare Housing with Holes

Figure 2 shows the five machined holes for various input and output cables. Circle 1 is for the NI DAQ printer cable. Circle 2 is for the USB to Serial connection. Circle 3 is for the GPS wires. Circle 4 is for the input voltage lines. Circle 5 is for the power supply cables. Additionally, 8 more holes were drilled on the bottom of the box to act as the mounting points for the FluxPMU board itself. The six holes shown in Figure 3 were traced, and lined up in the housing to create 6 mounting points.
Figure 3: FluxPMU Mounting Holes

The other two holes were added for the NI DAQ USB-6009. Once screws, washers, and plastic mounts that raised the board off of the metal housing were obtained, the FluxPMU board and NI DAQ were mounted. Additionally, the DIN rail was cut to 6 inches, and mounted with two screws above the input side of FluxPMU (above circle 4 in Figure 2). The power supply was simply attached to the DIN rail for ease of use. Finally, a clear plastic sheet was added to the top of the mourning to add safety to the user and protection for the board and all of it’s components.

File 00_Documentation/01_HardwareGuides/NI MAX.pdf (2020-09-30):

Using NI MAX

The purpose of this document is to show how to use NI MAX, and how to configure your NI USB 6009 OEM for testing use.

To begin, you will need NI MAX (National Instruments Measurement and Automation Explorer.) The program should have been downloaded with LabVIEW. To open it, find it via the search function on the Windows Toolbar by typing “ni max.” Once you open NI MAX, you should get a window like:

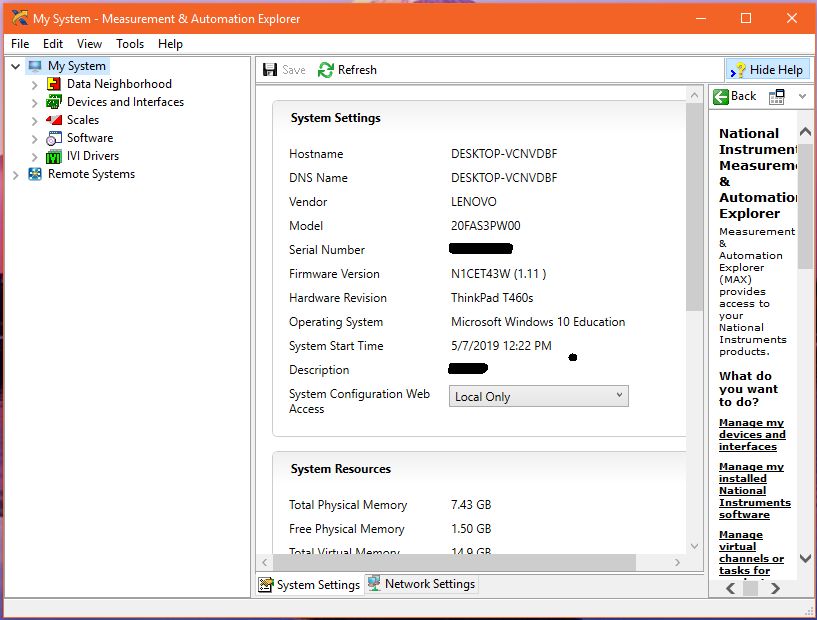
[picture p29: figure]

In order to use NI MAX, you will need to plug in your USB 6009 to your computer. You will need a USB A to USB B cable to connect the computer to the USB 6009. Once the USB 6009 is connected to your computer, you should get the following pop-up window.

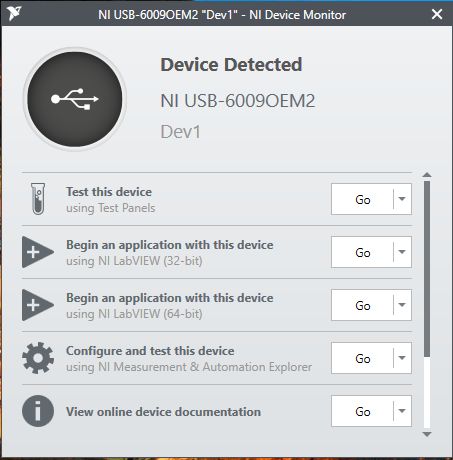
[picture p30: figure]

The pop-up is a similar application to NI MAX, but not as useful for our applications. Feel free to either close the pop-up, or click Go under “Configure and test this Device” which opens another instance of NI MAX. In NI MAX, under My System open Devices and Interfaces. You should see a new device as shown below. You’ll notice that the device is known as “Dev1”

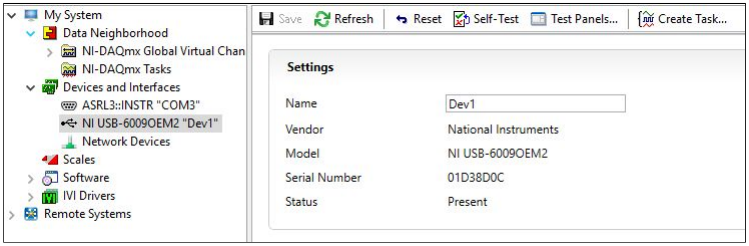
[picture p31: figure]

Click on Test Panels… to open the following window.

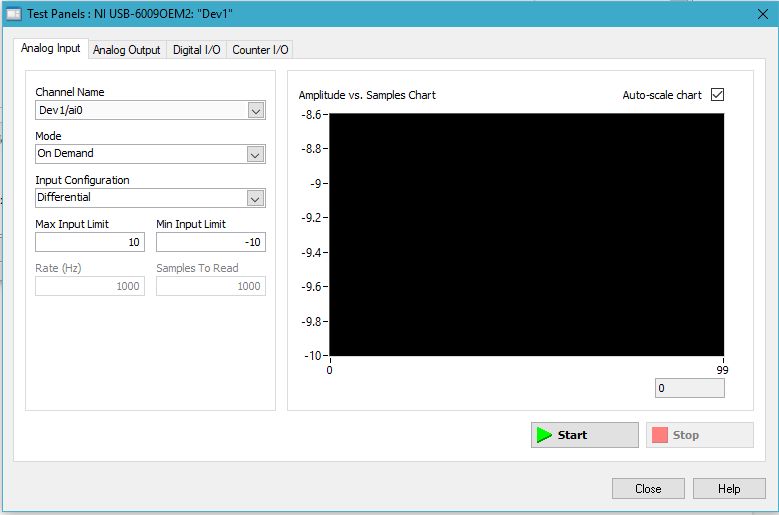
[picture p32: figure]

This window will allow you to test any of the I/O that the USB-6009 can do.

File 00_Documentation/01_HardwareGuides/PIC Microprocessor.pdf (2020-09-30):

## PIC18F2525 Instructions

The document below gives instructions on how to program the PIC18F2525 Microprocessor. The document starts with the process on how to compile the code provided by OpenPMU. The method of uploading code is discussed afterwards.

### Compilation

1. Begin by downloading version 8.50 or later MPLAB IDE from http://www.microchip.com/development-tools/pic-and-dspic-downloads-archive You will have to create an account to do so, which is free. Make sure to download any version 8.50 or higher. Scroll to the MPLAB ARCHIVES section to find the version you want.
2. Download the compiler from https://www.microchip.com/Developmenttools/ProductDetails/SW006011 Choose the Standard Eval Version. When installing the compiler, when asking for the directory, install the compiler to C:\Program Files (x86)\Microchip\MCC18\ or C:\Program Files\Microchip\MCC18\ depending on what you downloaded.
3. Download the folder OpenPMU PIC - V5.1 if you haven't already or move the folder to an easily accessible location. (I saved it to my Desktop.)
4. Open MPLAB IDE. File → Open Workspace… → testbenh.mcw and open the workspace. Click OK to the missing file notification.
5. Make or Build the project once. A Tool-Location Discrepancy window will open. Click the MPLAB IDE → Use This option. The build should fail.
6. In the workspace, testbenh.mcw window, find the Linker Script folder. Right click on the file 18f2525.lkr and select Locate Missing File → Use a file of my own choosing → Follow the path:
C: → Program Files (x86) → Microchip → MCC18 → bin → LKR → 18f2525_g.lkr and open the file 18f2525_g.lkr as your new file.
7. Go to Project → Build Options… → Project → MPLINK Linker. Check the box Use Alternate Settings and change the input from
/m"$(BINDIR_)$(TARGETBASE).map" /w /o"$(BINDIR_)$(TARGETBASE).cof"
to
/m"$(BINDIR_)$(TARGETBASE).map" /w /p18f2525 /o"$(BINDIR_)$(TARGETBASE).cof"
Ensure there are spaces like:... /w /p18f2525 /0… not .../w/p18f2525/o...
8. Make or Build again. There will be a syntax error in the code dml_common.c Double click on the error line to open dml_common.c or go to File → Open → dml_common.c The error here is odd, and must be something specific to the compiler. The code must end with a blank line. To resolve the syntax error, simply add a blank line to the end of the code, after the comment and save it. Close dml_common.c.

9. Make or Build again, and when the Tool-Location Discrepancy windows open, click the MPLAB IDE Use This option again. The build should now succeed.
10. If the build still fails, go to Project → Build Options… → Project → Directories. In the drop down menu for Show directories for: under Include Search Path and Library Search Path, ensure that the program files is either C:\Program Files\... or C:\Program Files (x86)\... is consistent with your other settings.

### Uploading Code

To start the process of programming the PIC you will need the completed, populated PCB Board. The board itself will be used to program the PIC, so you don’t need to buy any sort of PIC programming base or kit. To program the PIC, begin by plugging the chip into the 28 Pin IC Socket. The 5 pin PCB header, shown below, will be connected to the PICkit 3.

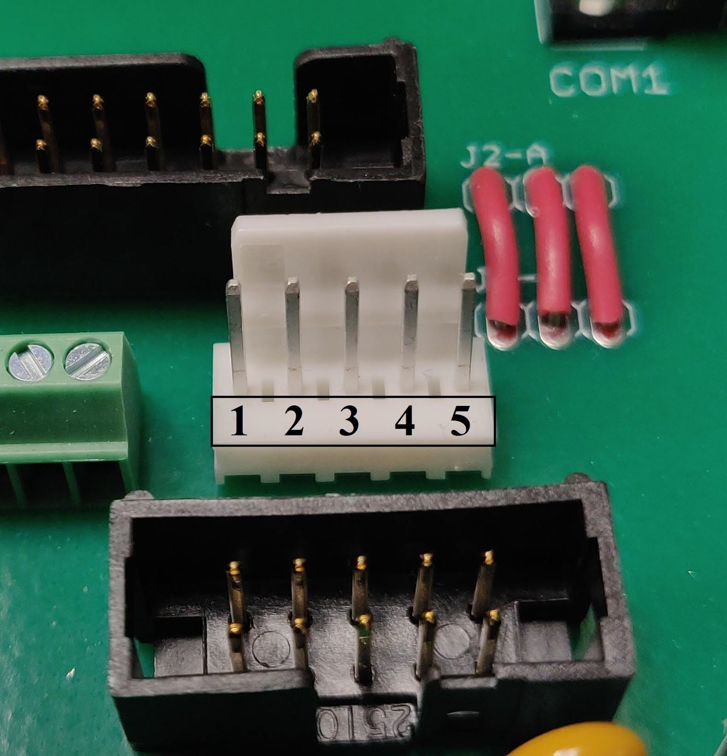
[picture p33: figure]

The 5 pin PCB header has the following pins:
1 | 2 | 3 | 4 | 5
Ground | Vcc (VDD Target) | MCLR | PGC | PGD

The PICkit 3 has the following pinout:

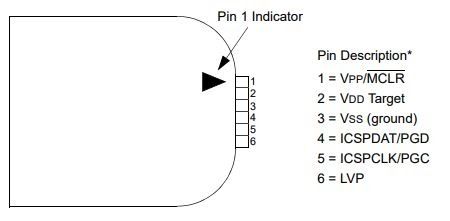
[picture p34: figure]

Because the pinouts are not in the same configuration/order, you will need to use the PCB programming cable to connect the correct input and outputs. You will need to cut the ribbon cable to connect each wire to the correct input. The set up should look like the following.

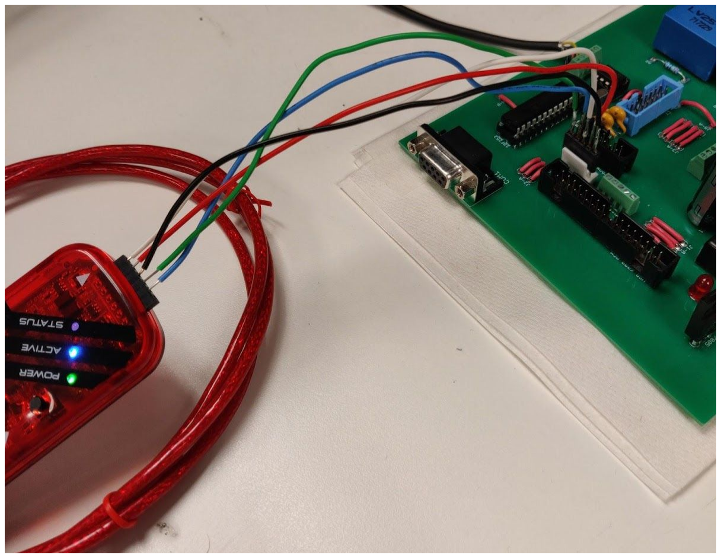
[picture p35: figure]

The image above shows a recreation of my connection to the board. Note that the GPS is connected to the board in the picture, however it should NOT be connected when programming the PIC. Also note, that the wired connection is not the same as the one in the parts list.
Connect the PICkit 3 to your computer.
Before you start any programming, the USB-6009 OEM MUST BE DISCONNECTED. The voltages used by PICkit 3 may be able to damage the USB-6009 OEM.
Disconnect the GPS from the board as well if you have connected it. Better to be safe than sorry.

Open MPLABS IDE v8.50. Go to File → Open Workspace.... And open the compiled testbenh.mcw that you compiled earlier. In the upper toolbar, go to Programmer → Select

Programmer → PICkit 3. In the Output window, an output should print “PICkit 3 detected.” More lines will be outputted. Once “PICkit 3 Connected” is outputted, if not using a universal seat, you should get an error. To solve the error go to Programmer → Settings → Power → Check the box “Power target circuit from PICkit 3” and make sure the Voltage is set at 5V. Click Apply, and OK when the warning window pops up. (If you get any sort of detection errors, make sure all of the pins of the 18F2525 entered their respective port. I had several problems with pins not being lined up correctly, and bending, breaking the connection.)
A new group of icons in the toolbar should become available to the right. Click Program. Once programming is complete, click Verify. The output window should be something similar to the image below. Once you have finished uploading the code, make sure to go back to Programmer → Settings → Power → and uncheck the power button.

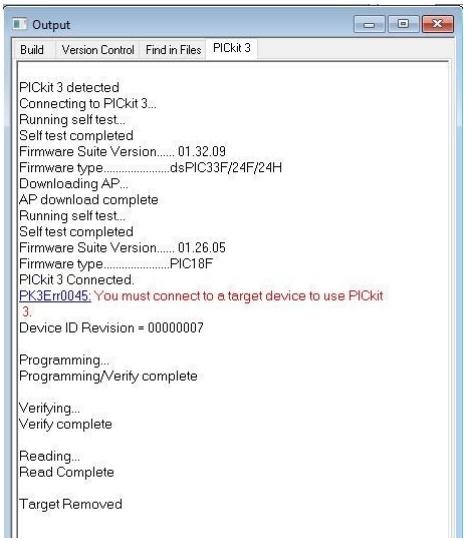
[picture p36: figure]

The PIC should now be ready to communicate data. To verify that the programming was completed correctly, if you haven’t already, disconnect all PIC communications including the PICkit 3. Plug in the RS-232 communications cable to COM1 of the board, and to your computer. You will now need access to the program HyperTerminal or HyperAccess. In this explanation I am using HyperAccess. There is a free demo for 30 days for HyperTerminal that you can download here: https://www.hilgraeve.com/hyperterminal/ HyperTerminal should perform the same functionality for our purposes as HyperAccess.
Open Windows Device Manager. In the device manager, find out which com port the board is communicating with by looking through the
Ports (COM & LPT) section. The connection is called “Prolific USB-to-Serial Comm Port” followed by the port used. In this example, I connect to COM6.
Open your Hyper program (Terminal or Access.) Go to File → New… and create a “New Entry Description”. Enter a name for the program, don’t change the “Notebook:” from Phonebook or “Terminal:” from ANSI as their inputs.

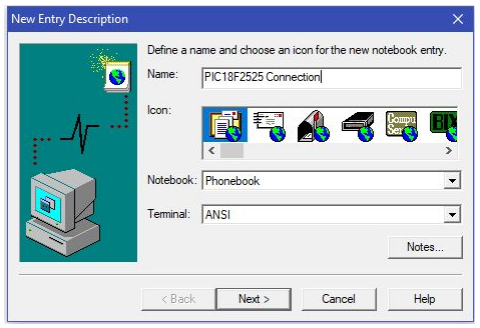
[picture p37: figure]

Click Next. Now, click the “Change…” box to connect to the COMM port found via the device manager. If not already selected, click on Direct Cabled COMX → Modify Connection… In the new window click “Change…” again, and in the final window “Connect Through” select the correct port. Once selected, click OK until you are back to the “New Entry Connection” window. Click Next. Change the connection settings to:
Bits per second: 4800
Data bits: 8
Partiy: None
Stop Bits: 1
Flow Control: None

Once set, Click OK → Next → Finish. In the main menu of HyperAccess, your new connection settings will be created. Double-click your settings to open it. HyperAccess will now automatically connect, so disconnect the program. The Telephone buttons in the upper left-hand corner can be used to connect and disconnect. If you haven’t already set up the power supplies, do so now via the document “Power Supplies Example”.
Once the power supplies is set up, but not plugged in, connect with HyperAccess. Plug in the power supplies, and you should get an output similar to the following:

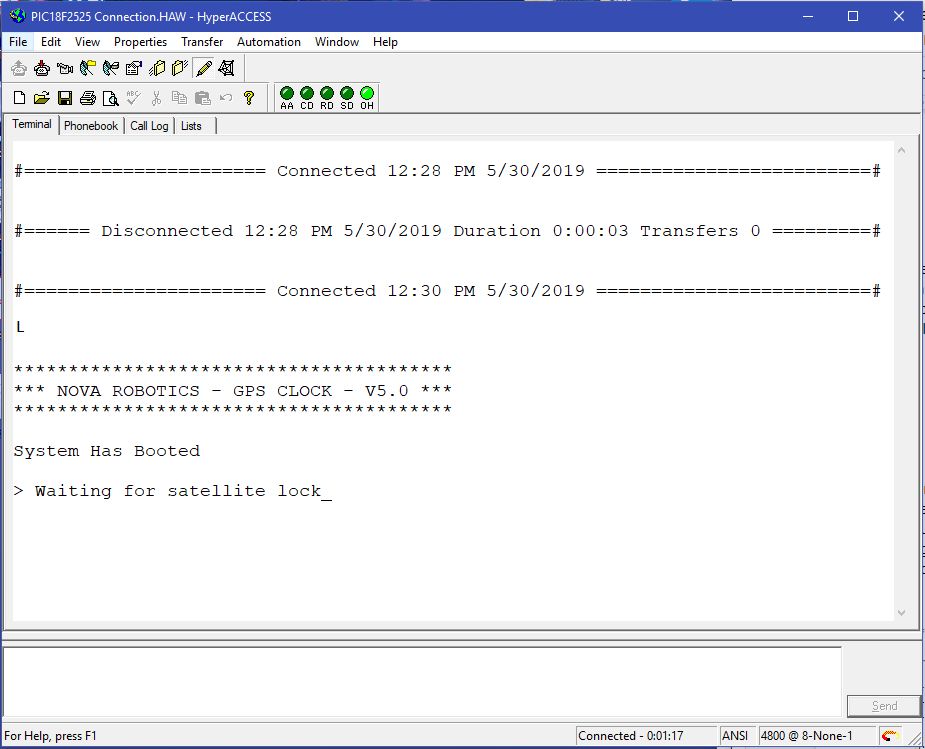
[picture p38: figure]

If you get this output, congrats, the PIC18F2525 has been programmed correctly.

Note: In order to get the output shown above, you must first Connect with HyperAccess, and then turn on the power supplies. Turning the power to the board off and on does not seem to output a message. If the board is powered first, and then you Connect with HyperAccess, no output message will be shown.

Whenever you would like to reconnect to the GPS, you can change the port selection from HyperAccess via Properties → Communication. You may have to do this whenever you connect to the GPS, as Comm ports can change even when using the same physical port on your computer.

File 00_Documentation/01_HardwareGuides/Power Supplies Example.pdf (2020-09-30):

## Creating the Power Supplies

The purpose of this document is to show you an example of how the power source can be constructed with the components given.

As shown in the image below, the power supply is connected to the DIN Rail, along with several other cable connections. These however are not necessary to operate OpenPMU. The Power supplies must still be set up and plugged in correctly, which is shown in this document. To start creating the the DIN power rail, you will need to cut the DIN rail into 20 cm long lengths, as shown below. To do so, I had a faculty member use a bandsaw to cut the rail. Take the DIN rail terminals and attach them to the rail as shown below.

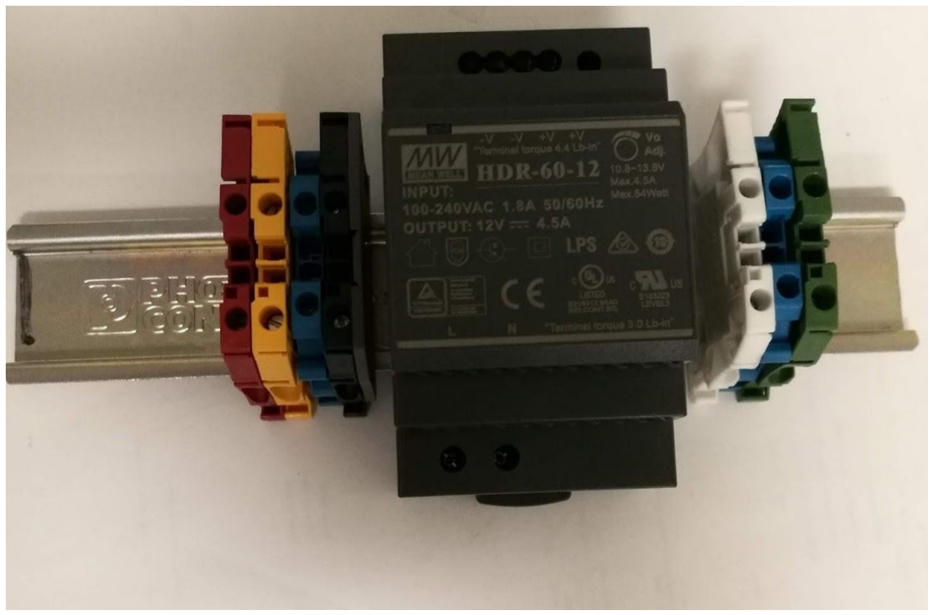
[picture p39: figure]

The purpose of the DIN rail and all of the components on it are as follows.
1. To supply voltage and power to the circuit board itself via the 12V power supply.
2. To send the AC voltages to each transformer via the Red, Yellow, and Blue DIN rail mounts.
3. Supply the AC voltages to both the circuit board as stated above, and the power supply via the White, Blue, and Green DIN mounts.
1) Make sure to use Stranded wire
2) I used gauge 22 wire. Whatever you use, make sure it is stranded wire, not a core wire. Begin by getting around 1.5 to 2 feet of wire. Take the cables, strip the ends, and tin

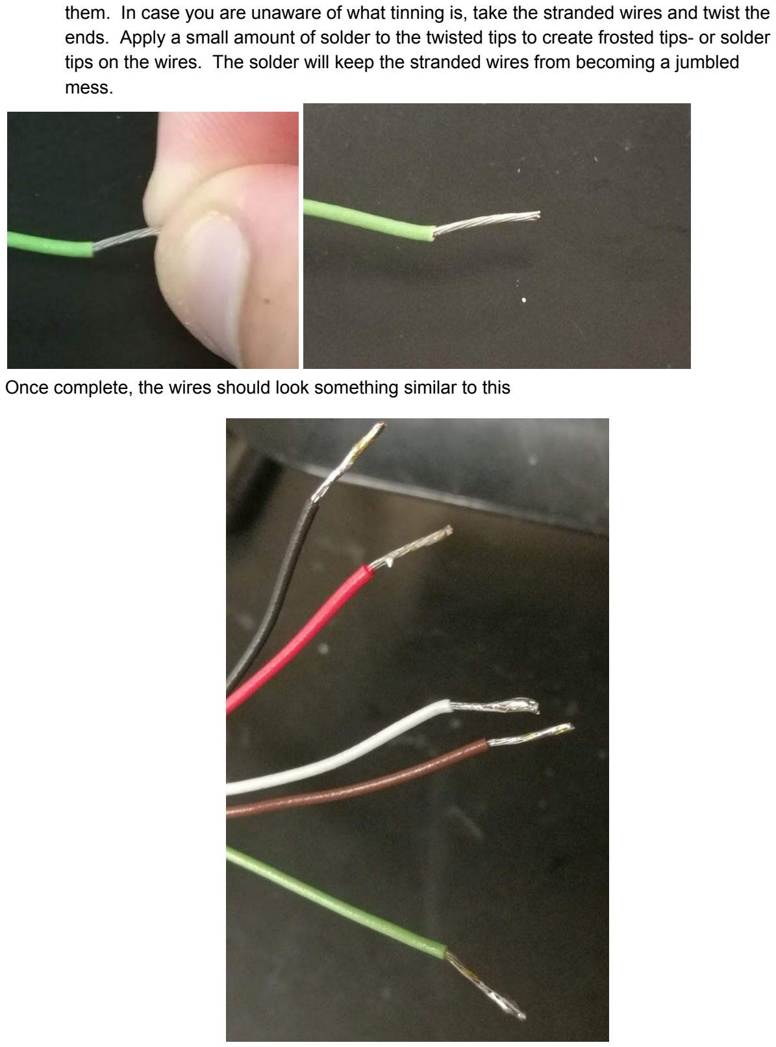
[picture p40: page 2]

them. In case you are unaware of what tinning is, take the stranded wires and twist the ends. Apply a small amount of solder to the twisted tips to create frosted tips- or solder tips on the wires. The solder will keep the stranded wires from becoming a jumbled mess.

Once complete, the wires should look something similar to this

### Powering Using the DIN Rail

To power the power supply itself you must start with a cable and For instance, and the one I used, you must get a cable such as the one below.
One side of the cable is plugged into standard North America plugs. The other side are standard European Union wire colors which follow: Brown is the Active line, Blue is the Neutral line and Green/Yellow is the Ground Line. If you have a different cable, you will have to look up the corresponding cables and cable colors.

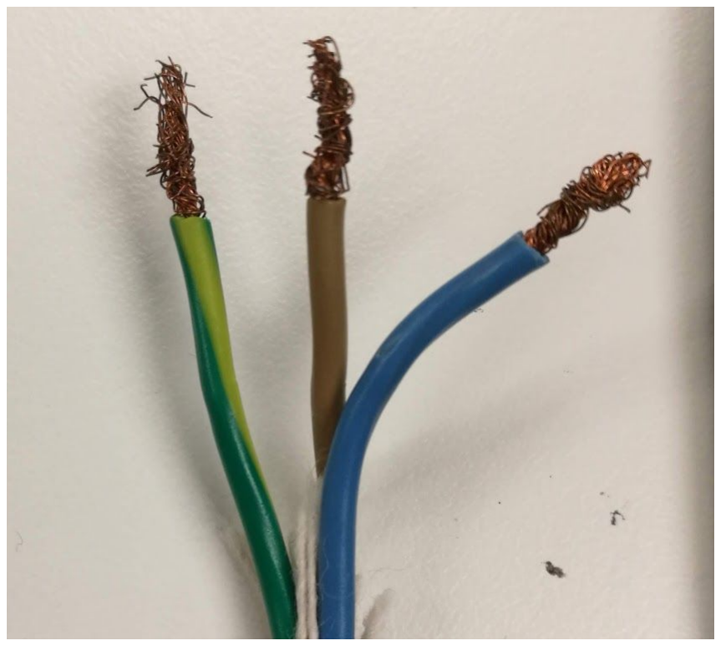
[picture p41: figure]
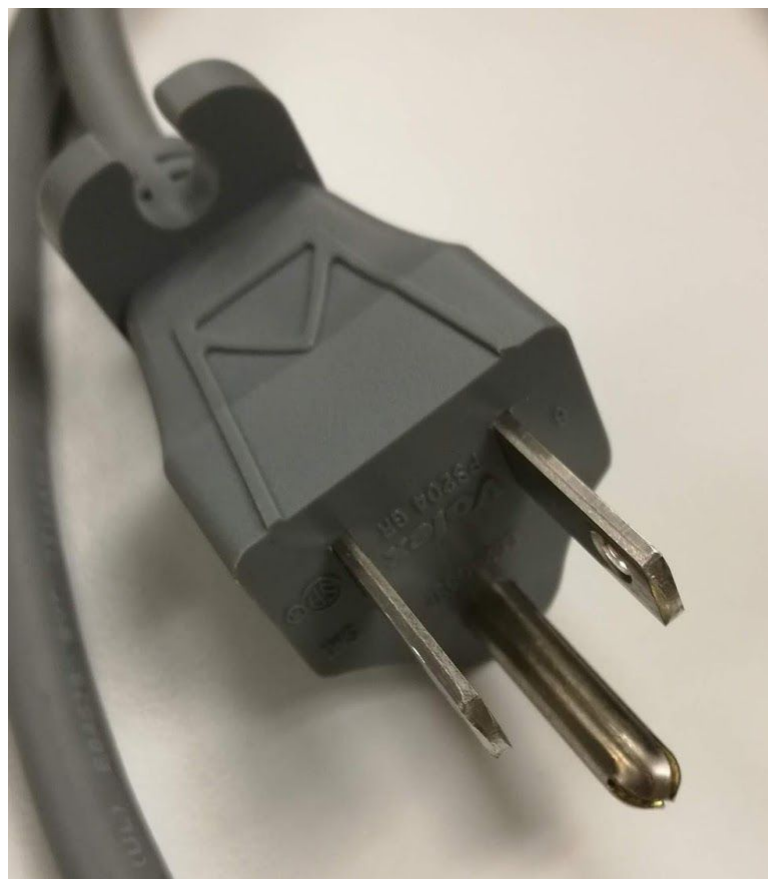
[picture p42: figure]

To plug in and power the power supply, begin by loosening the screw on the bottom of the power supply. Notice which screw corresponds to the Line and Neutral (L) and (N).
CAUTION: You are now using AC Line voltages, which are dangerous and could hurt/kill you. Before moving onto the next the section, make sure that your cable is not plugged into the wall

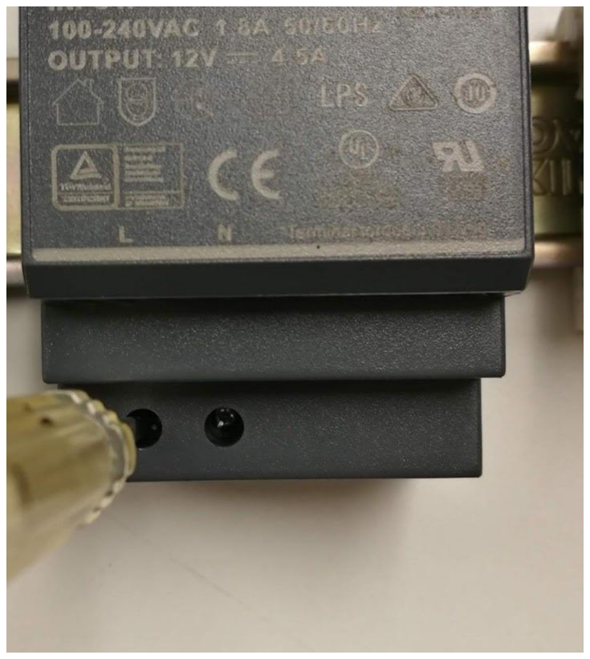
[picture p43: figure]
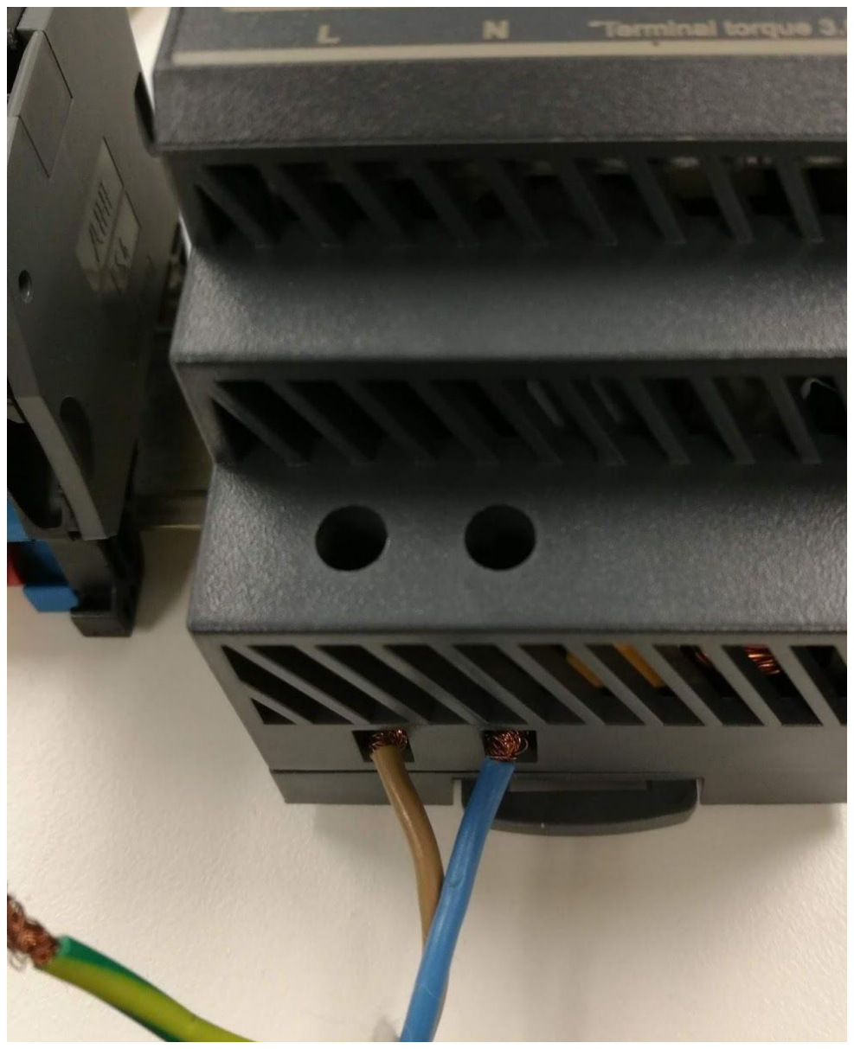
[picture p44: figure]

outlet when working with the bare wires. A suggested practice is to tape the unused wire to your work top, to ensure it doesn’t move or short with anything.

Next, you will need two more wires to power the board, coming from the power supply and connecting to the board itself. In the images below, +V is the Brown wire and -V is the silver wire. Make sure that your positive wire and negative wires are plugged in correctly like that of below.

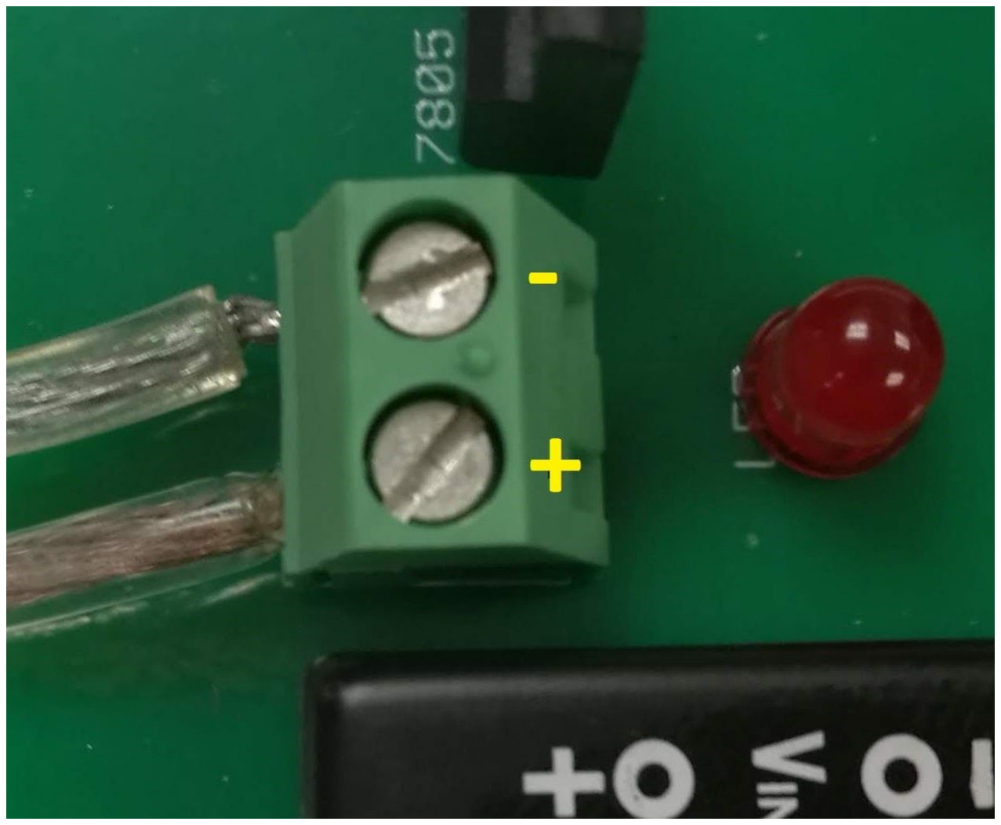
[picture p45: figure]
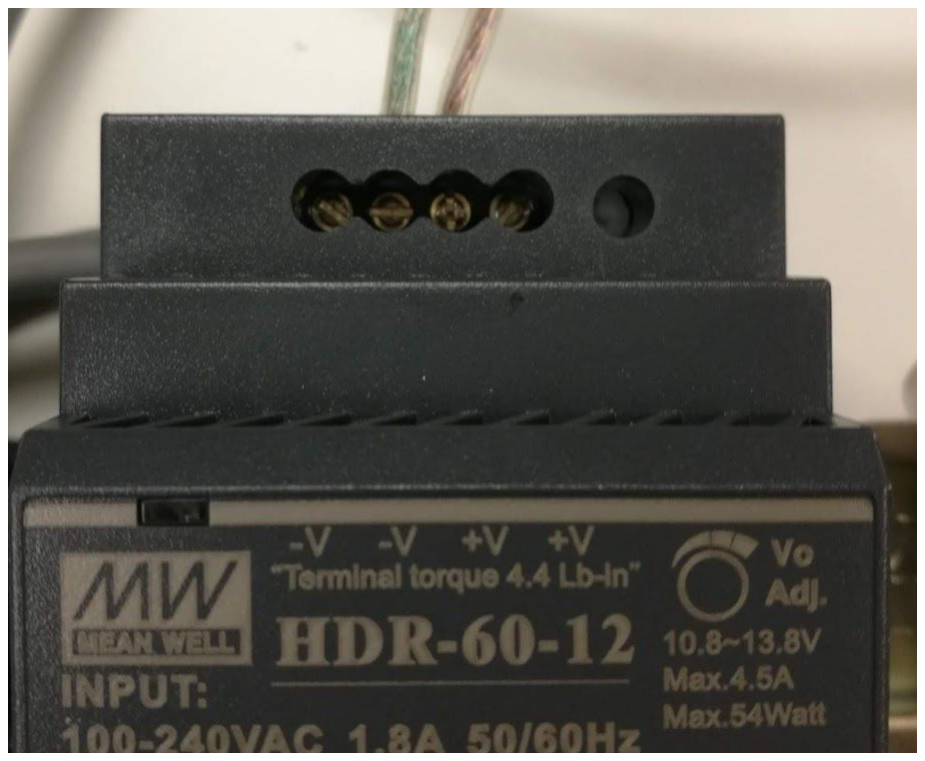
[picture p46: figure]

Once all wires are plugged in, plug in the power supply power cable into the wall outlet. The Red LED will turn on, and you may hear several clicks coming from the power supply.

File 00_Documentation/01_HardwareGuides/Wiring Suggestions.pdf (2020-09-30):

Simulated Signal from a Frequency Generator

The purpose of this document is to provide information on connecting the wires for several components of OpenPMU.

Ribbon Cable Construction

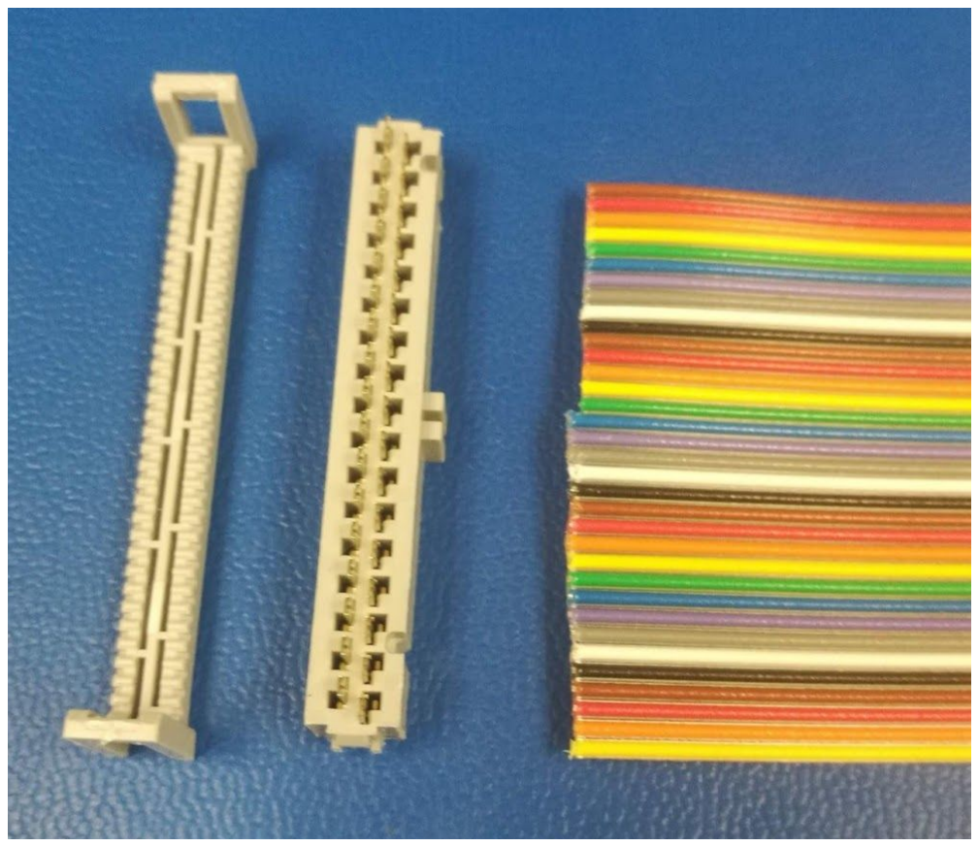
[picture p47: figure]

Start by obtaining the USB-6009 OEM IDC Socket with 34 contacts, and at least 5 inches (12 cm) of ribbon cable, cut to 34 individual wires.

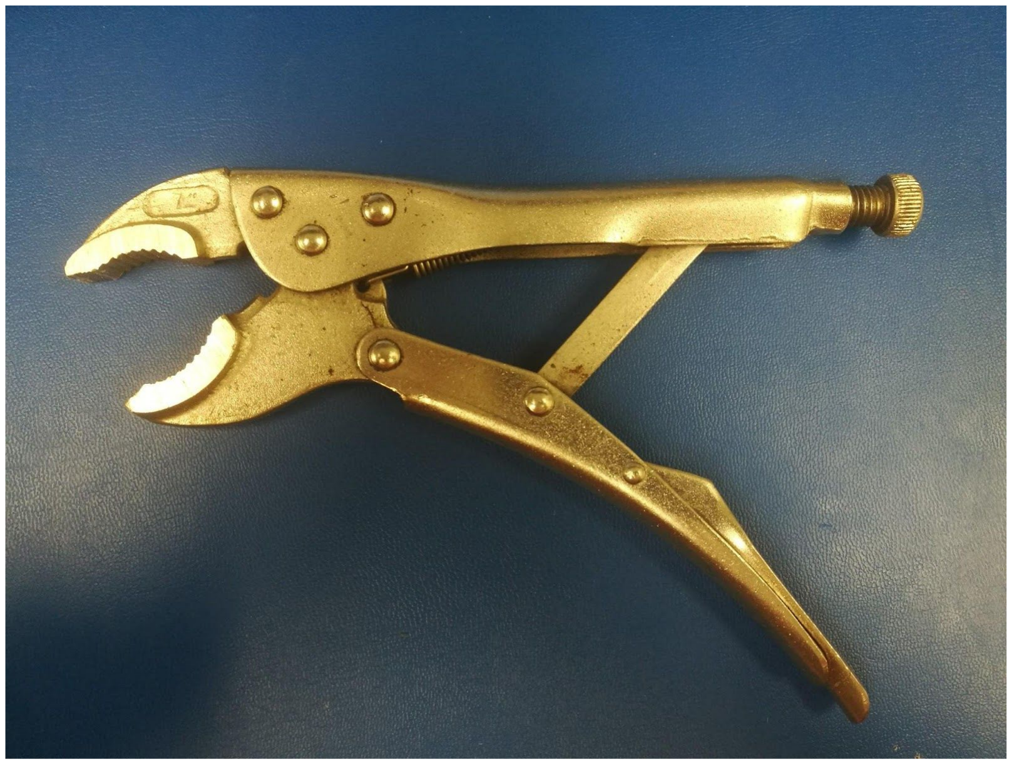
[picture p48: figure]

To connect the ribbon cable and the IDC Socket, you will need something similar to the vice grip shown to the right.


Take the ribbon cable and sandwich it between the
socket and the stress relief.

ATTENTION: Wear some sort of eye protection when connecting the the ribbon cable to the IDC socket, as the stress relief may break.


ATTENTION: Make sure that each wire has a corresponding connection before using the vice grip to
clamp the connectors together.


ATTENTION: Ensure that the notch is pointing in the same direction as your ribbon cables. If it is not, you will have to start over. The notch is circled in the image below.


Start on the edges, and with force, clamp the stress relief down with the vice grip. Continue to clamp the stress relief down, making sure the top is level, and every connection is established. When complete, as shown, there are no visible copper connectors. Carefully insert the IDC socket into your USB-6009.


The image to the left shows the ribbon cable successfully added to the IDC socket. Notice that there are no visual connectors.

Tinning


Here is an example of how to “tin” wires, which involves stranded cables. You will need to start by stripping the end of a stranded wire. With your fingers, twist the end of the stranded cable to combine all of the strands into one. Apply a small amount of solder to the twisted end to create a homogenous wire, similar to the images shown below.


The twisted stranded wires:


When applying the solder, your wires should look something similar to the image to the right.

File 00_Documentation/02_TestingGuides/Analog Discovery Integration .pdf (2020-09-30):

## Using Analog Discovery 2

The purpose of this document is to show how to use an Analog Discovery 2 to set up waveforms, similar to a waveform generator. Note, that you can only create a single signal with the analog discovery, as the device itself only has two waveform outputs.

### Hardware

To set up the hardware you will need the Analog Discovery 2 (AD), the rainbow cables that come with it, the NI USB 6009 OEM and all other cables to connect the two devices to your computer. To connect the AD to the USB 6009, simply plug the waveform cable directly on to the pin/port you would like. Shown below., I connected W1 to AI 2 of the USB 6009 OEM. The pin diagram of the USB 6009 OEM is also shown.


### Software

To actually set up the connection, open NI MAX, and if you don’t have it installed, download and install and open Digilent/ Analog Discovery WaveForms. In WaveForms, select Wavegen, and modify the settings to an appropriate waveform (50-60 Hz, 1 V amplitude). Make sure to select an offset that makes sense (I had to set mine to around + 1.35 V). In NI MAX, navigate to your NI-DAQmx Tasks, and select the appropriate Analog Input. Run NI MAX, then run WaveForms. You should get something similar to the following: Also, when finished, make sure to stop both WaveForms and NI MAX.


You should now be able to open the VI 00 Main Simulated Signal and run the VI to see the output from the Analog Discovery. Make sure to set your input task ports to the correct AI input in the Sub VI 14 Function Generator Signal.

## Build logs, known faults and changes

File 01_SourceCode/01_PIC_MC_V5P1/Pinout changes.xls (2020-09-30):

RD5 | becomes | RB2 | PLL Output
RD6 | becomes | RB3 | PLL Speed Select 1
RD7 | becomes | RB4 | PLL Speed Select 2

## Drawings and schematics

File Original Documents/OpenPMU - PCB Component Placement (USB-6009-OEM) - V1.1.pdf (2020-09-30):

+

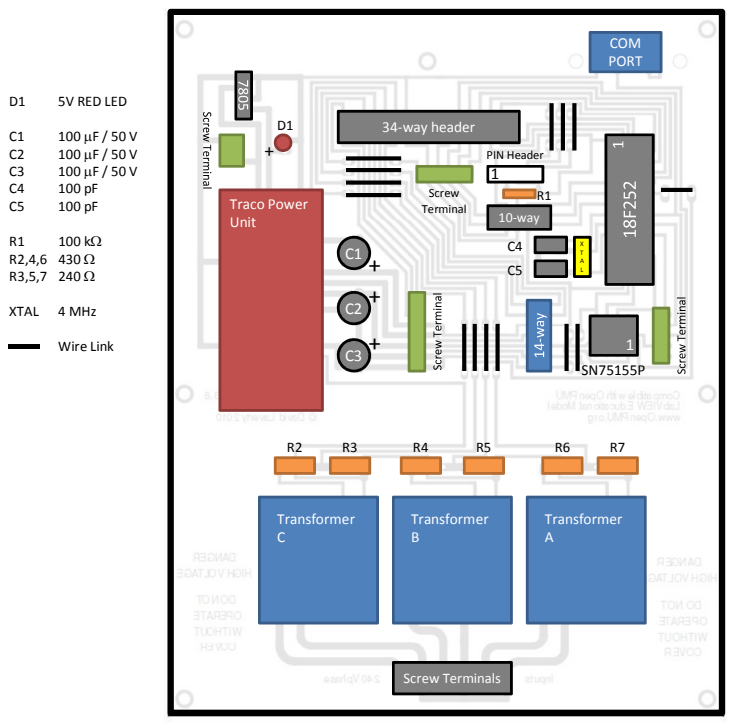
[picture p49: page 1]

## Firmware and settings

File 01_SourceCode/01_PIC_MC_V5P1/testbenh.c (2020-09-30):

//////////////////////////////////////////////////////////////
//	Source for Nova Robotics GPS Clock (with PPL)			//
//	Version 5.0 - For 18F252 Device							//
//	30/06/2010												//
//////////////////////////////////////////////////////////////
//
// Global Variables
//
unsigned int PPS_initial_time = 0;
unsigned int PPS_total_time = 0;
unsigned int PPS_high_time = 0;
int years = 0;
int months = 0;
int days = 0;
int hours = 0;
int minutes = 0;
int seconds = 0;
int lock = 0;
int lock_hour = 0;
int lock_mins = 0;
int timecheck = 0;

//$GPRMC,040302.663,A,3939.7123,N,10506.6123,W,0.27,358.86,200804,,*1A
char position[] =    "                        ";

// Header Files
//
#include <p18f2525.h>
#include <timers.h>
#include <usart.h>
#include <stdlib.h>
#include <delays.h>
#include <stdio.h>
#include <string.h>
#include <math.h>
#include <portb.h>
#include "dml_common.c"	// David's useful functions
#include "gps_232.c"	// Reads the GPRMC line of NMEA
#include "pps_time.c"	// Accurate 1PPS time keeping

// Pre-processor Instructions
//
#pragma config OSC = HSPLL				// - set HS oscillator
#pragma config WDT = OFF, WDTPS = 128	// - enable watchdog timer
#pragma config LVP = OFF				// - disable low voltage programming
#pragma config DEBUG = ON				// - enable background debugging

// Function Prototypes
//
void setup(void);
void bootup(void);
void time_stamp(void);
void read_time(void);
void num2txt(long, long);

//-------------------------------------------------------------
// -- Setup
void setup(void){

	ADCON1 = 0b00001110;			// Set PORTA 1.2.3 for LCD IO

	Delay10TCYx( 5 );				// Wait a moment
		    //76543210
	TRISA = 0b11110011;				// Port A IO
	TRISB = 0b11110011;				// Port B IO
	TRISC = 0b11001111;				// Port C IO
	
	OpenTimer0(TIMER_INT_OFF &		// Open Timer0
		T0_16BIT & 
		T0_SOURCE_INT & 
		T0_PS_1_128);

	OpenTimer1(TIMER_INT_ON & 		// Open Timer1
		T1_16BIT_RW & 
		T1_SOURCE_INT & 
		T1_PS_1_4);
	
	OpenUSART (USART_TX_INT_OFF &	// Open the USART
		USART_RX_INT_OFF &
		USART_ASYNCH_MODE &	
		USART_EIGHT_BIT &			// Configured as 8N1, in polled mode
		USART_CONT_RX &
		USART_BRGH_HIGH, 207);		// 4800 Baud (using clock multiplier)*/

	OpenRB0INT (PORTB_CHANGE_INT_ON & 	// Enable the RB0/INT0 interrupt
		PORTB_PULLUPS_ON & 				// Configure the RB0 pin for input
		RISING_EDGE_INT); 				// Trigger interrupt upon falling edge
	
	OpenRB1INT (PORTB_CHANGE_INT_ON & 	// Enable the RB0/INT0 interrupt
		PORTB_PULLUPS_ON & 				// Configure the RB0 pin for input
		RISING_EDGE_INT); 				// Trigger interrupt upon falling edge

	RCONbits.IPEN = 0;				// Enable interrupt priority
	IPR1bits.RCIP = 0;				// Make receive interrupt low priority
	IPR1bits.TMR1IP = 1;			// Set to low priority Interrupt
	INTCONbits.GIEH = 1;			// Enable all high priority interrupts
	INTCONbits.GIEL = 1;			// Enable all low priority interrupts
}

// ************* MAIN *************
//
void main(void){

	int i = 0;

	Delay10KTCYx(100);
	setup();

	INTCONbits.GIEH = 0;		// INTERRUPTS
	INTCONbits.GIEL = 0;		// OFF

	PORTAbits.RA2 = 0;
	PORTAbits.RA3 = 1;
	PORTAbits.RA4 = 1;

	bootup();

	PLL_speed();									// Check required PLL speed	
			
	WriteTimer1(0);

	INTCONbits.GIEH = 1;		// INTERRUPTS
	INTCONbits.GIEL = 1;		// ON

	while(1){
		
		if( seconds == 0 && timecheck == 0 ){		// Check the GPS receiver's time once a minute
			read_time();
			timecheck = 1;	
		}
		else if( seconds >= 1 && timecheck == 1 ){
			timecheck = 0;
		}			

		if( Clock1 == 0 && Tick1 == 0){				// Output a 'tick' to the RS232 port
			if(lock == 1){ putrsUSART((const far rom char *)"*"); }
			else{ putrsUSART((const far rom char *)"-"); }
			PORTAbits.RA3 = seconds%2;				// Toggle RD6 to indicate 1PPS transition
			Tick1 = 1;

			PLL_speed();							// Check required PLL speed
		}
		else if( Clock1 != 0 ){
			Tick1 = 0;
		}

		if( RB0_flag == 1 ){						// Service the request for a time stamp
			time_stamp();
		}
	
	}
}

//-----------------------------------------------------
// TIME STAMP
//
void time_stamp(void){

	char temp_txt[] = "          ";
	int i = 0;
	int j = 0;

	// $CLOCK,<hh:mm:ss.mmm>,<dd/mm/yy>,<lock (A/V)>,<PLL Freq>,<lat>,<log>,<lock - hh:mm>*
	
	RB0_time = (int) (1000 * (float) RB0_time / (float) PPS_total_time);

	putrsUSART((const far rom char *)"\n\r$CLOCK,");
	num2txt( hours,2 );
	putrsUSART((const far rom char *)":");
	num2txt( minutes,2 );
	putrsUSART((const far rom char *)":");
	num2txt( RB0_secs,2 );
	putrsUSART((const far rom char *)".");
	num2txt( RB0_time,3 );
	putrsUSART((const far rom char *)",");
	num2txt( days,2 );
	putrsUSART((const far rom char *)"/");
	num2txt( months,2 );
	putrsUSART((const far rom char *)"/");
	num2txt( years,2 );
	putrsUSART((const far rom char *)",");

	if(lock == 1){
		putrsUSART((const far rom char *)"A");
	}
	else{
		putrsUSART((const far rom char *)"V");
	}
	putrsUSART((const far rom char *)",");
	num2txt( Freq1,2 );
	putrsUSART((const far rom char *)",");
	
	i = 0;
	j = 0;
	while( j == 0 ){
		
		if(position[i] == 'E' || position[i] == 'W'){ 
			j = 1;
		}
		putcUSART( position[i] );
		while( BusyUSART() );
		i++;	
	}
	putrsUSART((const far rom char *)",");
	num2txt( lock_hour,2 );
	putrsUSART((const far rom char *)":");
	num2txt( lock_mins,2 );
	putrsUSART((const far rom char *)"*");

	RB0_flag = 0;
}

//-----------------------------------------------------
// READ TIME
//
void read_time(void){

	read_gps();							// is received, and time can be assumed valid.
	seconds = seconds - 1;					// Time seems to be 1 second ahead of UTC without this correction
	PORTAbits.RA2 = lock;					// Indicate lock on RD7
}

//-------------------------------------------------------------
// -- BOOT UP
void bootup(void){
										
	putrsUSART((const far rom char *)"\n\r");
										//0123456789012345678901234567890123456789
	putrsUSART((const far rom char *)"\n\r****************************************");
	putrsUSART((const far rom char *)"\n\r*** NOVA ROBOTICS - GPS CLOCK - V5.0 ***");
	putrsUSART((const far rom char *)"\n\r****************************************");
	putrsUSART((const far rom char *)"\n\r");
	putrsUSART((const far rom char *)"\n\rSystem Has Booted");
	putrsUSART((const far rom char *)"\n\r");
	putrsUSART((const far rom char *)"\n\r> Waiting for satellite lock");

	lock = 0;
	while(lock == 0){					// Run the Read_GPSlock fucntion until a satellite fix
		read_gps();						// is received, and time can be assumed valid.
	}

	putrsUSART((const far rom char *)"\n\r> Satellite lock established");
	putrsUSART((const far rom char *)"\n\r> Calibrating to 1PPS reference");
	
	while( PORTBbits.RB0 == 1 );
	while( PORTBbits.RB0 == 0 );
	WriteTimer0(0);
	while( PORTBbits.RB0 == 1 );
	PPS_high_time = ReadTimer0();			// Duration of the '1' in the 1PPS
	while( PORTBbits.RB0 == 0 );
	PPS_total_time = ReadTimer0();			// Total period of the 1PPS
	PPS_initial_time = ReadTimer0();		// Total period of the 1PPS

	putrsUSART((const far rom char *)"\n\r>> PPS_total_time ");
	num2txt(PPS_total_time,5);
	putrsUSART((const far rom char *)"\n\r>> PPS_high_time  ");
	num2txt(PPS_high_time,5);

	putrsUSART((const far rom char *)"\n\r> Reading NMEA Format Time  ");

	read_time();

	putrsUSART((const far rom char *)"\n\r");
	putrsUSART((const far rom char *)"\n\r*****************************");
	putrsUSART((const far rom char *)"\n\r*** ");
	num2txt(hours,2);
	putrsUSART((const far rom char *)":");
	num2txt(minutes,2);
	putrsUSART((const far rom char *)":");
	num2txt(seconds,2);
	putrsUSART((const far rom char *)" - ");
	num2txt(days,2);
	putrsUSART((const far rom char *)"/");
	num2txt(months,2);
	putrsUSART((const far rom char *)"/20");
	num2txt(years,2);
	putrsUSART((const far rom char *)" ***");
	putrsUSART((const far rom char *)"\n\r*****************************");
	putrsUSART((const far rom char *)"\n\r");

}

// ********* END OF FILE **********
